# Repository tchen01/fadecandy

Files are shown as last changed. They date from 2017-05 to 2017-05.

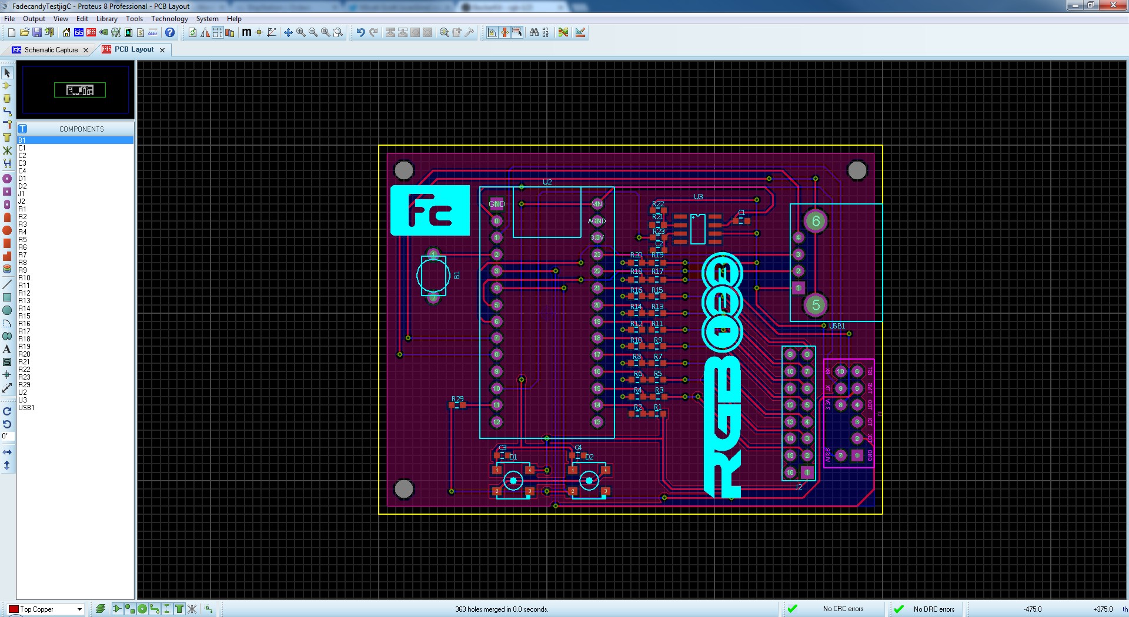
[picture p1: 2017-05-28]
pcb/testjig/FadeCandyTestJigC_ScreenCapture.jpg

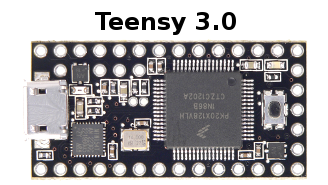
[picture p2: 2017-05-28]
pcb/teensy3/wiring-diagram.graffle/image1.png

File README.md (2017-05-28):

Fadecandy Title

Fadecandy is a project that makes LED art easier, tastier, and more creative. We're all about creating tools that remove the technical drudgery from making LED art, freeing you to do more interesting, nuanced, and creative things. We think LEDs are more than just trendy display devices, we think of them as programmable light for interactive art.

* [Video Introduction to Fadecandy](https://vimeo.com/79935649)
* [Introduction by Nick Poole from Spark Fun Electronics](https://www.youtube.com/watch?v=-4AUBjV7Y-w)
* [Tutorial: LED Art with Fadecandy](https://learn.adafruit.com/led-art-with-fadecandy)
* [Tutorial: 1,500 NeoPixel LED Curtain with Raspberry Pi and Fadecandy](https://learn.adafruit.com/1500-neopixel-led-curtain-with-raspberry-pi-fadecandy/)
* [Presentation slides: Easier and Tastier LED Art with Fadecandy](http://www.misc.name/easier-and-tastier-led-art-with-fadecandy/)
* [LED Interaction Research with Fadecandy at Stimulant labs](http://stimulant.com/led-interaction-research/)

Buy a Fadecandy Controller board:

* [Adafruit](http://www.adafruit.com/products/1689)
* [RGB-123](http://rgb-123.com/product/fadecandy/)



Simple Example
--------------

Here's a simple project, a single LED strip controlled by a Processing sketch running on your laptop:

Fadecandy system diagram 1

```
// Simple Processing sketch for controlling a 64-LED strip.
// A glowing color-blob appears on the strip under mouse control.

OPC opc;
PImage dot;

void setup()
{
  size(800, 200);

  // Load a sample image
  dot = loadImage("color-dot.png");

  // Connect to the local instance of fcserver
  opc = new OPC(this, "127.0.0.1", 7890);

  // Map one 64-LED strip to the center of the window
  opc.ledStrip(0, 64, width/2, height/2, width / 70.0, 0, false);
}

void draw()
{
  background(0);

  // Draw the image, centered at the mouse location
  float dotSize = width * 0.2;
  image(dot, mouseX - dotSize/2, mouseY - dotSize/2, dotSize, dotSize);
}
```

A More Complex Example
----------------------

Fadecandy is also useful for larger projects with many thousands of LEDs, and it's useful for art that runs on embedded computers like the Raspberry Pi:

Fadecandy system diagram 2

Project Scope
-------------

This project is a collection of reusable pieces you can take or leave. The overall goal of making LED art easier, tastier, and more creative is a broad one. To keep this project manageable to start with, there are some rough limitations on what's supported:

* LED strips, grids, and other modules based on the WS2811 or WS2812 chip.
  * Common and inexpensive, available from [many suppliers](http://www.aliexpress.com/item/5M-WS2811-LED-digital-strip-60leds-m-with-60pcs-WS2811-built-in-tthe-5050-smd-rgb/635563383.html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) for around $0.25 per pixel.
* Something with a USB host port that can run your art.
  * Laptops and Mac Minis work great
  * The Raspberry Pi is also a great platform for this, but it requires more technical skill
* Distances of no more than 60ft or so between your computer and your farthest LEDs
  * USB cables < 50ft
  * WS2811 data cables < 10ft
* No more than about 10000 LED pixels total
  * There's no hard limit, but it gets more difficult after this point.

These are fuzzy limitations based on current software capabilities and rough electrical limits, so you may be able to stretch them. But this gives you an idea about the kind of art we try to support. Projects are generally larger than wearables, but smaller than entire buildings.

For example, the first project to use Fadecandy was the [Ardent Mobile Cloud Platform](http://scanlime.org/2013/09/the-ardent-mobile-cloud-platform/) at Burning Man 2013. This project used one Raspberry Pi, five Fadecandy controller boards, and 2500 LEDs.

Fadecandy makes no assumptions about how you generate control patterns for the LEDs. You can generate a 2D video and sample pixels from the video, you can make a 3D model of your sculpture and sample a 3D *shader* for your pixel values, or you can create a unique system specifically for your art.

Fadecandy Controller
--------------------

The centerpiece of the Fadecandy project is a controller board which can drive up to 512 LEDs (as 8 strings of 64) over USB. Many Fadecandy boards can be attached to the same computer using a USB hub or a chain of hubs.

Fadecandy makes it easy to drive these LEDs from anything with USB, and it includes unique algorithms which eliminate many of the common visual glitches you see when using these LEDs.

The LED drive engine is based on Stoffregen's excellent [OctoWS2811](http://www.pjrc.com/teensy/td_libs_OctoWS2811.html) library, which pumps out serial data for these LED strips entirely using DMA. This firmware builds on Paul's work by adding:

* A high performance USB protocol
* Zero copy architecture with triple-buffering
* Interpolation between keyframes
* Gamma and color correction with per-channel lookup tables
* Temporal dithering
* A custom PCB with line drivers and a 5V boost converter
* A fully open source bootloader

These features add up to give *very smooth* fades and high dynamic range. Ever notice that annoying stair-stepping effect when fading LEDs from off to dim? Fadecandy avoids that using a form of [delta-sigma modulation](http://en.wikipedia.org/wiki/Delta-sigma_modulation). It rapidly wiggles each pixel's value up or down by one 8-bit step, in order to achieve 16-bit resolution for fades.

Vitals
------

* 512 pixels supported per Teensy board (8 strings, 64 pixels per string)
* Very high hardware frame rate (~400 FPS) to support temporal dithering
* Full-speed (12 Mbps) USB
* 257x3-entry 16-bit color lookup table, for gamma correction and color balance

Platform
--------

Fadecandy uses the Freescale MK20DX128 microcontroller, the same one used by the [Teensy 3.0](http://www.pjrc.com/store/teensy3.html) board. Fadecandy includes its own PCB design featuring a robust power supply and level shifters. It also includes an open source bootloader compatible with the USB Device Firmware Update spec.

You can use Fadecandy either as a full hardware platform or as firmware for the Teensy 3.0 board.

Color Processing
----------------

Fadecandy internally represents colors with 16 bits of precision per channel, or 48 bits per pixel. Why 48-bit color? In combination with our dithering algorithm, this gives a lot more color resolution. It's especially helpful near the low end of the brightness range, where stair-stepping and color *popping* artifacts can be most apparent.

Each pixel goes through the following processing steps in Fadecandy:

* 8 bit per channel framebuffer values are expanded to 16 bits per channel
* We interpolate smoothly from the old framebuffer values to the new framebuffer values
* This interpolated 16-bit value goes through the color LUT, which itself is linearly interpolated
* The final 16-bit value is fed into our temporal dithering algorithm, which results in an 8-bit color
* These 8-bit colors are converted to the format needed by OctoWS2811's DMA engine
* In hardware, the converted colors are streamed out to eight LED strings in parallel

The color lookup tables can be used to implement gamma correction, brightness and contrast, and white point correction. Each channel (RGB) has a 257 entry table. Each entry is a 16-bit intensity. Entry 0 corresponds to the 16-bit color 0x0000, entry 1 corresponds to 0x0100, etc. The 257th entry corresponds to 0x10000, which is just past the end of the 16-bit intensity space.

Keyframe Interpolation
----------------------

By default, Fadecandy interprets each frame it receives as a keyframe. In-between these keyframes, Fadecandy will generate smooth intermediate frames using linear interpolation. The interpolation duration is determined by the elapsed time between when the final packet of one frame is received and when the final packet of the next frame is received.

This scheme works well when frames are arriving at a nearly constant rate. If frames suddenly arrive slower than they had been arriving, interpolation will proceed faster than it optimally should, and one keyframe will hold steady until the next keyframe arrives. If frames suddenly arrive faster than they had been arriving, Fadecandy will need to jump ahead in order to avoid falling behind.

This keyframe interpolation is not intended as a substitute for other forms of animation control. It is intended to generate high-framerate video from a source that operates at typical video framerates.

Open Pixel Control Server
-------------------------

The Fadecandy project includes an [Open Pixel Control](http://openpixelcontrol.org/) server which can drive multiple Fadecandy boards and DMX adaptors. USB devices may be hotplugged while the server is up, and the server uses a JSON configuration file to map OPC messages to individual Fadecandy boards and DMX devices.

Why use Open Pixel Control?

* You can keep your effects code portable among different lighting controllers.
* OPC includes an OpenGL-based simulator, allowing you to develop effects before the hardware is done.
* The OPC server manages USB hotplug and multi-device synchronization, so you don't have to.
* The OPC server loads color-correction data into each Fadecandy board.

WebSockets Server
-----------------

In addition to Open Pixel Control, `fcserver` also supports WebSockets, so you can write LED art algorithms and utilities in Javascript using the plethora of libraries and tools available on that platform. LED art can be easily integrated with any input device or library that will run in the browser or Node.

Browser UI
----------

When you run `fcserver`, it also gives you a simple browser-based UI for identifying the attached Fadecandy Controllers and quickly testing your lights. By default, this UI runs on [http://localhost:7890](http://localhost:7890).

Browser UI Screenshot

Where to?
---------

* [Video introduction by Nick Poole from Spark Fun Electronics](https://www.youtube.com/watch?v=-4AUBjV7Y-w)
* Tutorial: ["LED Art with Fadecandy"](https://learn.adafruit.com/led-art-with-fadecandy)
* Sample projects are in [examples](https://github.com/scanlime/fadecandy/tree/master/examples)
* Pre-compiled binaries are in [bin](https://github.com/scanlime/fadecandy/tree/master/bin)
* More documentation is included in [doc](https://github.com/scanlime/fadecandy/tree/master/doc)
  * [Open Pixel Control Protocol](https://github.com/scanlime/fadecandy/blob/master/doc/fc_protocol_opc.md)
  * [WebSocket Protocol](https://github.com/scanlime/fadecandy/blob/master/doc/fc_protocol_websocket.md)
  * [USB Protocol](https://github.com/scanlime/fadecandy/blob/master/doc/fc_protocol_usb.md)
  * [Processing OPC Client](https://github.com/scanlime/fadecandy/blob/master/doc/processing_opc_client.md)
  * [Server Configuration](https://github.com/scanlime/fadecandy/blob/master/doc/fc_server_config.md)
  * ...or if you still have questions, ask the [discussion group](https://groups.google.com/forum/#!forum/fadecandy)
* Buy a Fadecandy Controller board
  * [Adafruit](http://www.adafruit.com/products/1689)
  * [RGB-123](http://rgb-123.com/product/fadecandy/)

Frequently Asked Questions
--------------------------

### Why can't you use more than 64 LEDs per strip?

This limit comes from the data rate of the WS2811 LED controller's protocol (800 kbps) and the frame rate that seems to be needed to get the best results from our temporal dithering algorithm (about 400 FPS).

With the WS2811 protocol, each bit takes 1.25 microseconds to transmit, and there's a 50 microsecond reset state that happens once per frame. Each LED has 24 bits of data. We can use this to relate number of LEDs to frames per second:

```
(a)   fps = 1 / ( 0.00000125 * 24 * numLEDs + 0.00005 )
(b)   numLEDs = floor( (1 / fps - 0.00005) / 0.00000125 / 24 )
```

Equation (a) tells us that the theoretical maximum frame rate for 64 LEDs is 507.6 FPS. The Fadecandy Controller actually gets more like 425 FPS most of the time, since the CPU speed tends to be the limiting factor. With Equation (b), we can see that a theoretical strip length of 81 would still let us get 403 FPS. So why did I choose 64 instead of 81? Powers of two, mostly, and I honestly chose the limit of 64 before I knew exactly what frame rates would be necessary.

It would be possible to drive LED strips of around 80 LEDs in length with the same quality using a slightly more powerful microcontroller, as long as we don't rely on the strip length to be a power of two.

### Will Fadecandy work on the Teensy 3.1 board?

Currently, no. The Teensy 3.1 uses a different microcontroller with a slightly different memory layout which would make it impractical to have one firmware image that's binary-compatible with both the Teensy 3.1 and the Teensy 3.0 / Fadecandy Controller board. This is a thing that's certainly doable, but I haven't wanted to spend the extra maintenance effort to maintain and test a binary image for a second architecture.

If anyone reading is passionate about supporting the Teensy 3.1 and would volunteer to maintain a port, I'd be happy to point you toward the modifications that would be necessary.

### Would Fadecandy be able to take advantage of the additional processing power on the Teensy 3.1's microcontroller?

A little bit, maybe! But it wouldn't be a dramatic improvement, if we wanted to keep the exact same quality of dithering.

With some extra processing power and RAM, the strip length limit could be increased from 64 to around 80. This is hardly a dramatic increase, though. The intrinsic limits explained above are more of a factor in the design than the CPU or RAM limits.

### Can you use multiple Fadecandy controllers at once?

Yes! You can use USB hubs to connect many Fadecandy boards to one controller.

### What are the limits? How big can Fadecandy go?

Fadecandy limits include USB bus bandwidth, Open Pixel Control packet size, and CPU power. 

USB Bus bandwidth will start to be a problem around a dozen Fadecandy boards per USB host controller. This may start to depend on the details of the computer you're using. On a laptop, each USB port will usually have an independent allocation of bandwidth available. So, connect the first dozen Fadecandy boards to one USB port, then the second dozen to another USB port, etc. If you do connect more than the recommended number of Fadecandy controllers to one port they'll still work, but frame rate will start to decrease.

The [Open Pixel Control](http://openpixelcontrol.org/) protocol used by Fadecandy has a packet size limit of 64 kilobytes, or 21845 LEDs. Any more than that will require workarounds, such as extending the OPC protocol or using multiple OPC channels.

And then there's CPU power... these limits will depend on the language and framework your code uses, and what kind of computer you're running from. A large installation with 10,000 LEDs will probably need to run off of a laptop or Mac Mini unless your code is quite efficient. Smaller installations with up to 1000 LEDs or so could run off of something as small as a Raspberry Pi. But these are very broad generalizations, and this all depends on how much processing you need to perform per-LED. Keep in mind the scalability levels of your particular framework when you plan to build a large installation.

### The Raspberry Pi is kind of slow. What other small embedded Linux computers are available?

There are a lot of options to choose from, but my current favorite is the [ODROID-U3](http://www.hardkernel.com/main/products/prdt_info.php?g_code=G138745696275). It's about the same size as a Raspberry Pi, with a 1.7 GHz quad-core ARM. There's an optional fan add-on, but I haven't found it to be necessary yet.

### I'm using Windows 7, and the driver for Fadecandy doesn't load. What can I do?

Make sure you have all available Windows updates installed. Fadecandy uses a Windows feature ([WCID](https://github.com/pbatard/libwdi/wiki/WCID-Devices)) that wasn't present in the original retail version of Windows 7, but it was added in a subsequent update.

For reference, this is a 
[series of screenshots](http://imgur.com/a/0MAFR) showing a Fadecandy controller attached to a freshly installed Windows 7 Home Professional 32-bit virtual machine. At first it fails (no driver for "Fadecandy") but after updating Windows, it finds the correct device (WinUSB) and fcserver connects to it.

If that doesn't fix it, you may have a version of Windows with an inexplicably broken `WinUSB` driver. The French version of Windows 7 SP1 seems to be afflicted by this bug, and possibly others. As a workaround, you can use the [Zadig](http://zadig.akeo.ie/) utility to manually install an alternative driver. Use the arrows to change the driver on the right side of the arrow from `WinUSB` to `libusbK`, then click "Install Driver". You can see a [series of screenshots](http://imgur.com/a/25V81) illustrating this.

If you're still having trouble, please ask for help on the [discussion group](https://groups.google.com/forum/#!forum/fadecandy) or [bug tracker](https://github.com/scanlime/fadecandy/issues) and we can get to the bottom of this problem together. Thanks for your patience!

Contact
-------

Please direct questions to the [Discussion group](https://groups.google.com/forum/#!forum/fadecandy), it's full of smart and creative people who can help!

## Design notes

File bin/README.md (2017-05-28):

Fadecandy: Pre-compiled Binaries
================================

This directory contains convenient precompiled firmware and server binaries for Fadecandy. This file explains the conventions for the various types of files here.

Fadecandy Server
----------------

* `fcserver-osx`
  * Ready-to-run fcserver for Mac OS 10.6 and later
* `fcserver.exe`
  * Ready-to-run fcserver for Windows 7 and later
* `fcserver-rpi`
  * Ready-to-run fcserver for Raspberry Pi
  * May also work on other ARM Linux distributions
  * Requires root privileges and/or special usbfs configuration

Firmware Images
---------------

* `fc-boot-v###.hex`
  * Bootloader image only, in Intel Hex format.
  * This can be combined with other images to create a bootloader plus firmware image, or you can burn it alone and flash firmware separately using dfu-util.
  * For use with Teensy Loader, JTAG debuggers, or the Testjig.
* `fc-firmware-v###.hex`
  * Firmware image, including bootloader, in Intel Hex format.
  * For use with Teensy Loader, JTAG debuggers, or the Testjig.
  * Since this includes the bootloader, it can be updated with dfu-util if necessary.
* `fc-firmware-v###.elf`
  * ELF binary for the firmware. Includes debug symbols. Does NOT include the bootloader.
  * For use with GDB. Also used to generate Testjig firmware images.
  * Mainly used as a source file for generating other types of firmware images. You probably won't use it directly.
* `fc-firmware-v###.dfu`
  * Firmware image for DFU firmware updates.
  * For use with dfu-util to update firmware without any special debug hardware.
  
Firmware Update Tool
--------------------

Firmware updates use the open source [dfu-util](http://dfu-util.gnumonks.org/) package.

Usage:

`$ dfu-util -D fc-firmware-v###.dfu`

* On Windows, you may need to run this multiple times as Windows will need to install drivers automatically for the Bootloader device.
* First the Fadecandy board will go into bootloader mode. The LED will light.
* Next, firmware will download. During this process, the LED blinks.
* When the firmware download is done, the LED will go dark.

For example:

	$ dfu-util -D fc-firmware-v106.dfu
	dfu-util 0.7

	Copyright 2005-2008 Weston Schmidt, Harald Welte and OpenMoko Inc.
	Copyright 2010-2012 Tormod Volden and Stefan Schmidt
	This program is Free Software and has ABSOLUTELY NO WARRANTY
	Please report bugs to dfu-util@lists.gnumonks.org
	
	Opening DFU capable USB device... ID 1d50:6082
	Run-time device DFU version 0101
	Found DFU: [1d50:6082] devnum=0, cfg=1, intf=0, alt=0, name="Fadecandy Bootloader"
	Claiming USB DFU Interface...
	Setting Alternate Setting #0 ...
	Determining device status: state = dfuIDLE, status = 0
	dfuIDLE, continuing
	DFU mode device DFU version 0101
	Device returned transfer size 1024
	Dfu suffix version 100
	bytes_per_hash=296
	Copying data from PC to DFU device
	Starting download: [##################################################] finished!
	state(7) = dfuMANIFEST, status(0) = No error condition is present
	state(7) = dfuMANIFEST, status(0) = No error condition is present
	...

* Windows: `dfu-util.exe` is included here, for convenience
* Mac OS: Install this with [homebrew](http://brew.sh): `brew install dfu-util`
* Linux: dfu-util is probably in your favorite package manager

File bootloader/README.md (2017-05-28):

Fadecandy Bootloader
====================

This is a simple open source bootloader for the Freescale Kinetis MK20DX128 microcontroller. It uses the USB Device Firmware Upgrade (DFU) standard. This bootloader was developed for use with Fadecandy, but it should be portable with to other projects using chips in the Kinetis microcontroller family.

Installing
----------

On a Teensy 3.0, you can use the Teensy Loader application to install `fc-boot.hex`. Afterwards, your Teensy should appear to the system as a "Fadecandy Bootloader" USB device capable of loading an application firmware image.

On a Fadecandy fc64x8 board, the bootloader can be installed via JTAG using OpenOCD. If you have an Olimex ARM-USB-OCD adapter, everything's already set up to install the bootloader with "make install". Other JTAG adapters will require changing `openocd.cfg`.

Application Interface
---------------------

This section describes the programming interface that exists between the bootloader and the application firmware.

The bootloader uses the smallest possible protected region on the MK20DX128's flash, a 4KB block. It uses a tiny amount of RAM for a "token" which is used to force entry into the bootloader on system reset.

When entering the application firmware, the system clocks will already be configured, and the watchdog timer is already enabled with a 10ms timeout. The application may disable the watchdog timer if desired.

The bootloader normally transfers control to the application early in boot, before setting up the USB controller. It will skip this step and run the DFU implementation if any of the following conditions are true:

* A banner ("FC-Boot\n") printed to the hardware UART at 9600 baud is echoed back within one character-period. (Manual entry by shorting TX and RX)
* A 32-bit entry token (0x74624346, or 'FCbt') is found at 0x2000_1FFC. (Programmatic entry)
* The application ResetVector does not reside within application flash. (No application is installed)

Memory address range       | Description
-------------------------- | ----------------------------
0x0000_0000 - 0x0000_0FFF  | Bootloader protected flash
0x0000_1000 - 0x0000_10F7  | Application IVT in flash
0x0000_1000 - 0x0001_FFFF  | Remainder of application flash
0x1FFF_E000 - 0x2000_1FFC  | Application SRAM
0x2000_1FFC - 0x2000_1FFF  | Entry token in SRAM

External Hardware
-----------------

No external hardware is required for the bootloader to operate. The following pins are used by the bootloader for optional features:

* PC5 is a status LED, active (high) while the bootloader is in DFU mode.
* PCR16/17 are set up as UART0 briefly during boot, for broadcasting the banner message and testing for manual bootloader entry.

File Format
-----------

The DFU file consists of raw 1 kilobyte blocks to be programmed into flash starting at address 0x0000_1000. The file may contain up to 127 blocks. No additional headers or checksums are included. On disk, the standard DFU suffix and CRC are used. During transit, the standard USB CRC is used.

Contact
-------

Micah Elizabeth Scott <<micah@scanlime.org>>

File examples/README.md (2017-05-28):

Fadecandy Example Code
======================

This directory contains sample projects and configuration files for Fadecandy.

* `processing`
  * Examples for [Processing 2](http://processing.org/), a popular tool for creative coding
* `html`
  * Browser-based examples, written in JavaScript with HTML5
* `node`
  * JavaScript examples for Node.js
* `cpp`
  * Examples written in C++
  * Includes a small header-only effects framework you can copy and reuse
  * Suitable for resource-constrained systems or very CPU-intensive patterns
  * Currently supports Linux and Mac OS X only.
* `python`
  * Some examples written in [Python](http://python.org/)
* `config`
  * Sample JSON configuration files for `fcserver`
* `layouts`
  * JSON layout files and layout generators
  * Compatible with the Open Pixel Control `gl_server`.
  * Compatible with some of the Node.js examples.

LED Layouts
-----------

Some examples are written for a specific LED layout or art project, some examples are general-purpose. For examples that use a specific LED layout, we indicate this with a naming convention. For example, if a project "potato" were written for a 48x24 grid, it would be named "grid48x24_potato".

Some of the generic examples (Specifically, the C++ and Node.js ones) can load separate layout files. These are in the same JSON notation used by the [Open Pixel Control](http://openpixelcontrol.org) project, and we use the same naming scheme for those JSON files.

Layout names we use so far:

* grid8x8 - A simple left-to-right top-to-bottom 8x8 pixel grid
  * For example, the [AdaFruit NeoMatrix](http://www.adafruit.com/products/1487)
* grid24x8z - Three 8x8 zig-zag grids side by side
  * Channel 0 is the center, and may be used alone.
  * For example, three of the 8x8 grids from [RGB-123](http://www.kickstarter.com/projects/311408456/rgb-123-led-matrices)
* grid32x8z - A 4x2 grid of 8x8 zig-zag grids
  * Channel 0 is the top-left grid, channel 7 is the bottom-right
  * For example, eight of the 8x8 grids from [RGB-123](http://www.kickstarter.com/projects/311408456/rgb-123-led-matrices)
* strip64 - A single 64-pixel LED strip
* triangle16 - A subdivided equilateral triangle with 16 pixels
* window6x12 - A complex window display layout made from glass blocks
  * This example shows how additional properties other than location may be stored in the JSON file.

More Examples
-------------

There are other places to look for example code too!

* The [Open Pixel Control](https://github.com/zestyping/openpixelcontrol) project
  * Everything here will work with Fadecandy, including their [Python examples](https://github.com/zestyping/openpixelcontrol/tree/master/python_clients)
* The [Ardent Mobile Cloud Platform source code](https://github.com/ArdentHeavyIndustries/amcp-rpi)
  * The [AMCP](http://scanlime.org/2013/09/the-ardent-mobile-cloud-platform/) is the first art project to use Fadecandy.
  * It controls 2500 LEDs with five Fadecandy boards and a Raspberry Pi.
  * The software is written in Python, with a C extension to accelerate the LED effects.
  * It's controlled over Wi-fi, by a [TouchOSC](http://hexler.net/software/touchosc) remote control.

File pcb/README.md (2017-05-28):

Fadecandy Controller Boards
===========================

This directory contains information and design files for the various circuit boards that you can run Fadecandy firmware on.

Teensy 3.0
----------

The [Teensy 3.0](http://www.pjrc.com/teensy/) microcontroller board from PJRC was the original development platform for Fadecandy. You can still run the Fadecandy firmware, including the bootloader, on this platform.

* Use the [Teensy Loader](http://www.pjrc.com/teensy/loader.html) to install a [Firmware Binary](https://raw.github.com/scanlime/fadecandy/master/bin/fc-firmware-v106.hex) on your Teensy 3.0
* Bridge pins 15 and 16
* Wire your LEDs according to the diagram:

**Warning:** The Teensy's output signals are 3.3V, whereas the WS2811 LEDs expect a 5V signal. It will often work anyway, but this tends to be unreliable if your LED power supply voltage isn't consistent or if your wires aren't very short.

Teensy 3.0 wiring diagram

Fc64x8 Revision A
-----------------
 
This board uses the same microcontroller as the Teensy 3.0 board, a Freescale Kinetis K20. There are several differences from the Teensy 3.0, however, that make it easier to use and more reliable for LED applications:

* It comes pre-programmed with the Fadecandy firmware.
* The Fadecandy board has a more convenient pinout, with more ground pads and with the LED strings organized sensibly.
* The Teensy uses 3.3v IO which doesn't work reliably with the WS2811 LEDs. Fadecandy includes a level shifter and series termination resistors.
* Fadecandy also includes a boost converter power supply to generate a stable 5V for the level shifter even when the USB power is noisy or sagging due to long cables.
* The Teensy uses a proprietary bootloader implemented on a separate microcontroller. The Fadecandy board has an open source bootloader that runs on the same microcontroller as the firmware, and it speaks the standard DFU protocol.

The PCB design for this revision is tagged as **fc64x8-rev-a** in Git. This board was manufactured in a limited run of 100, and availability has been very limited.

* [PCB Design Files](https://github.com/scanlime/fadecandy/tree/fc64x8-rev-a/pcb/fc64x8)
* Design software is [Eagle CAD](http://www.cadsoftusa.com/)

Fc64x8-a Photo

Fc64x8 Revision B
-----------------

Electrically the same as Revision A, this is the version produced by Adafruit. It is slightly larger, at 0.8" by 1.25". It uses a mini-USB instead of a micro-USB connector, and includes two extra small holes at the top corners for mounting onto larger boards.

RGB-123 Fadecandy Controller
----------------------------

This is a new board layout for Fadecandy which uses different component packages. It is produced and sold by Ryan O'Hara at RGB-123. The current version is Revision G.

Test Jig
--------

This board, with the help of a Teensy 3.0 and the testjig firmware, performs automated factory tests and firmware installation on Fadecandy boards.

The design was contributed by Ryan O'Hara of RGB-123.

* [Order PCBs via OSH Park](http://oshpark.com/shared_projects/0Hx8kSYR)
* Design software is [LabCenter Proteus](http://www.labcenter.co.uk/)

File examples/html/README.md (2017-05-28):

Fadecandy HTML5 Examples
========================

This directory contains examples for Fadecandy written in JavaScript with HTML5.

Stable Examples
---------------

* `grid8x8_dots`
  * A springy trail of glowing dots that follows the mouse
  * Uses [Paper.js](http://paperjs.org/)
  * Set up for an 8x8 grid in left-right top-down order
  * Browser support
    * **Firefox**: Works great
    * **Chrome**: Okay, but not as smooth as Firefox
    * **Safari**: Stops running after a couple seconds 

Additional Examples
-------------------

* `grid24x8z_dots` -- Modification of grid8x8 dots for the grid24x8z layout
* `grid24x8z_dots_leapmotion` -- Very experimental example with Leap Motion control

See Also
--------
 
* The fcserver Web UI
   * Uses the JSON interface to `fcserver`
   * Illustrates device hotplug, and bypassing the OPC pixel mapping
   * Try it out at [http://localhost:7890](http://localhost:7890) when fcserver is running
   * Source code at [fadecandy/server/http/js/home.js](https://github.com/scanlime/fadecandy/blob/master/server/http/js/home.js)

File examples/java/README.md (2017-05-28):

opc_client
==========

Simple Java OPC client for the [Fadecandy](http://www.misc.name/fadecandy/).
This is an alternative to the Processing client, providing a simpler interface similar to Adafruit's [NeoPixel library for Arduino](https://github.com/adafruit/Adafruit_NeoPixel).

# Writing simple pixel programs

Here is a simple Java program that will color some of the lights:

```
    public static void main(String[] args) throws Exception {
        OpcClient server = new OpcClient("10.28.46.61", 7890);
        OpcDevice fadecandy = server.addDevice();
        PixelStrip strip = fadecandy.addPixelStrip(0, 64);
        
        int color = 0xFF0000;  // red
        strip.setPixelColor(3, color);
        strip.setPixelColor(5, 0x888800); // yellow
        strip.setPixelColor(7, 0x00FF00); // green
        
        server.show();        // Display the pixel changes
        Thread.sleep(5000);   // Wait five seconds
        server.clear();       // Set all pixels to black
        server.show();        // Show the darkened pixels
        
        server.close();
    }
```

# Animations
We can also create Animation classes which will draw different patterns over and over.  We can attach animations to any given pixel strip.  When we attach a new animation object, the light patterns will change.

```
public class RandomPixels extends Animation {

    java.util.Random rand;
    
    public void reset(PixelStrip strip) {
        rand = new java.util.Random();
    }

    public boolean draw(PixelStrip strip) {
        int randomPixel = rand.nextInt(strip.getPixelCount());
        int randomColor = makeColor(rand.nextInt(255), 
                         rand.nextInt(255), rand.nextInt(255));
        strip.setPixelColor(randomPixel, randomColor);
        return true;
    }
}
```

# Server Configuration

The Fadecandy has eight pins, each of which can control a strip of 64 pixels.
If you have contiguous strips of pixels starting on pin zero, then your `fc_server` won't need to map the output pixels numbers to configurable OPC numbers.  However, if you have
shorter strips connected to different pins, you may want to set up a [JSON configuration file](https://github.com/scanlime/fadecandy/blob/master/doc/fc_server_config.md)
for the server.  The `OpcClient` class can print out a JSON configuration based on
strip definitions:

```
public static void main(String[] arg)  {
    OpcClient server = new OpcClient("raspberrypi.local", 7980);
    OpcDevice fadeCandy = server.addDevice();
        
    PixelStrip strip1 = fadeCandy.addPixelStrip(0, 64);  // 8 x 8 grid on pin 0
    PixelStrip strip2 = fadeCandy.addPixelStrip(1, 8);   // 8 pixel strip on pin 1
    PixelStrip strip3 = fadeCandy.addPixelStrip(2, 16);  // 16 pixel ring on pin 2
    PixelStrip strip4 = fadeCandy.addPixelStrip(3, 24);  // The first 24 pixels on pin 3
    PixelStrip strip5 = fadeCandy.addPixelStrip(3, 17);  // The next 17 pixels on pin 3
        
    // Since the pixels are not uniform strips of 64, customize 
    // the server config JSON file with the following:
    System.out.println(server.getConfig());
}
```

For the above setup, the JSON server configuration should be:

```
{
    "listen": [ "raspberrypi.local", 7890],
    "verbose": true,
    "devices": [
        {
            "type": "fadecandy",
            "map": [

                    [0, 0, 0, 64 ],
                    [0, 64, 64, 8 ],
                    [0, 72, 128, 16 ],
                    [0, 88, 192, 24 ],
                    [0, 112, 216, 17 ]
                ]
        }   ]
}
```

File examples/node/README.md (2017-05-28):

Fadecandy Node.js Examples
==========================

This directory contains examples for Fadecandy written in [Node.js](http://nodejs.org/).

Stable Examples
---------------

* `strip_redblue`
  * An example for LED strips. A fade of blue, white, and red washes across the LEDs.

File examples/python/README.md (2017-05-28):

Fadecandy Python Examples
========================

This directory contains examples for Fadecandy written in Python.

The Open Pixel Control project includes its own [Python examples](https://github.com/zestyping/openpixelcontrol/tree/master/python_clients). Those will all work with Fadecandy too.

Simple LED Patterns
-------------------

* `chase.py`
  * Light each LED in sequence
* `crosstalk-test.py`
  * Each LED strip glows dimly, and one strip at a time will briefly brighten.
  * The first three pixels of each strip indicate its position on the controller.
  * This is intended as a hardware test pattern to isolate any electrical interference issues between strips.
* `every-other-white.py`
  * Alternate between full-brightness and dark every other LED.
* `measuring-stick.py`
  * A tool for measuring LED strips.
  * The first LED in each group of 10 glows green.
  * All other LEDs in the strip are dark.
  * LEDs past the first 64 in the strip will be dark.
* `solid-white.py`
  * Fade all LEDs in to 100% brightness
* `strobe.py`
  * Rapidly fade all LEDs on and off

Other Samples
-------------

* `color-correction-ui.py`
  * Tk user interface for adjusting color correction settings.
  * Connects directly to `fcserver`
* `firmware-config-ui.py`
  * Tk user interface for firmware configuration settings.
  * Connects directly to `fcserver`
* `usb-lowlevel.py`
  * Demonstrates low-level USB control of a Fadecandy board, without `fcserver`.
  * Uses PyUSB

Sample Libraries
----------------

* `opc.py`
  * Original Open Pixel Control client
* `fastopc.py`
  * Higher-performance OPC client, using NumPy

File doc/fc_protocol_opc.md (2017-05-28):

Fadecandy: Open Pixel Control Protocol
======================================

The Fadecandy Server (`fcserver`) operates as a bridge between LED controllers attached over USB, and visual effects that communicate via a TCP socket.

The primary protocol supported by `fcserver` is [Open Pixel Control](http://openpixelcontrol.org), a super simple way to send RGB values over a socket. We support the standard Open Pixel Control commands, as well as some Fadecandy extensions.

Socket
------

Open Pixel Control uses a TCP socket, by default on port 7890. For the best performance, remember to set TCP_NODELAY socket option.

Command Format
--------------

All OPC commands follow the same general format. All multi-byte values in Open Pixel Control are in network byte order, high byte followed by low byte.

Channel    | Command   | Length (N) | Data
---------- | --------- | ---------- | --------------------------
1 byte     | 1 byte    | 2 bytes    | N bytes of message data

Set Pixel Colors
----------------

Video data arrives in a **Set Pixel Colors** command:

Byte   | **Set Pixel Colors** command
------ | --------------------------------
0      | Channel Number
1      | Command (0x00)
2 - 3  | Data length
4      | Pixel #0, Red
5      | Pixel #0, Green
6      | Pixel #0, Blue
7      | Pixel #1, Red
8      | Pixel #1, Green
9      | Pixel #1, Blue
…      | …

As soon as a complete Set Pixel Colors command is received, a new frame of video will be broadcast simultaneously to all attached Fadecandy devices.

Set Global Color Correction
---------------------------

The color correction data (from the 'color' configuration key) can also be changed at runtime, by sending a new blob of JSON text in a Fadecandy-specific command. Fadecandy's 16-bit System ID for Open Pixel Control's System Exclusive (0xFF) command is **0x0001**.

Byte   | **Set Global Color Correction** command
------ | ------------------------------------------
0      | Channel Number (0x00, reserved)
1      | Command (0xFF, System Exclusive)
2 - 3  | Data length (JSON Length + 4)
4 - 5  | System ID (0x0001, Fadecandy)
6 - 7  | SysEx ID (0x0001, Set Global Color Correction)
8 - …  | JSON Text

Set Firmware Configuration
--------------------------

The firmware supports some runtime configuration options. Any OPC client can send a new firmware configuration packet using this command. If the supplied data is shorter than the firmware's configuration buffer, only the provided bytes will be changed.

Byte   | **Set Firmware Configuration** command
------ | ------------------------------------------
0      | Channel Number (0x00, reserved)
1      | Command (0xFF, System Exclusive)
2 - 3  | Data length (Configuration Length + 4)
4 - 5  | System ID (0x0001, Fadecandy)
6 - 7  | SysEx ID (0x0002, Set Firmware Configuration)
8 - …  | Configuration Data

Current firmwares support the following configuration options:

Byte Offset | Bits   | Description
----------- | ------ | ------------
0           | 7 … 4  | (reserved)
0           | 3      | Manual LED control bit
0           | 2      | 0 = LED shows USB activity, 1 = LED under manual control
0           | 1      | Disable keyframe interpolation
0           | 0      | Disable dithering
1 … 62      | 7 … 0  | (reserved)

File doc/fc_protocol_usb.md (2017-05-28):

Fadecandy: USB Protocol
=======================

To achieve the best CPU efficiency, Fadecandy uses a custom packet-oriented USB protocol rather than emulating a USB serial device. This simple USB protocol is easy to speak using cross-platform libraries like [libusb](http://www.libusb.org) and [PyUSB](http://pyusb.sourceforge.net/). Examples are included.

If you use the included `fcserver` daemon, you need not worry about the USB protocol at all.

Device Information
------------------

Attribute       | Value
--------------- | -----
Vendor ID       | 0x1d50
Product ID      | 0x607a
Manufacturer    | "scanlime"
Product         | "Fadecandy"
Serial          | Unique ID string
Device Class    | Vendor-specific
Device Version  | See below
Configurations  | 1
Endpoints       | 1
Endpoint 1      | Bulk OUT (Host to Device), 64-byte packets

The Fadecandy device has one USB Configuration with two Interfaces:

* **Interface #0** is a vendor-specific interface with one Bulk OUT endpoint for communicating control data and video keyframes.
* **Interface #1** is compatible with the USB Device Firmware Update spec. It's used during firmware upgrade to ask the device to enter bootloader mode. During normal operation, it's safe to ignore this interface.

Some device version codes may be used to indicate experimental or unofficial firmware. Currently, versions in the range 0x0300 through 0x03FF are reserved for unofficial Fadecandy firmware forks.

Getting Started
---------------

To use the Fadecandy Controller's USB protocol directly, you'll need to:

1. **Search** for the device you're interested in. You can look for all Fadecandy devices by looking at the Vendor and Product IDs. You can find a specific Fadecandy device by looking at its USB serial number string.
3. **Open** the device, and set its configuration. Depending on the operating system, you may also need to claim interface #0 so your application has exclusive access to it.
4. Set up a **Color Look-Up Table**. There is no default table, the firmware expects you to calculate one based on the gamma and whitepoint you'd like to use.
5. Send **Video Frames** at any time. When you complete a frame, the firmware immediately begins interpolating to it.

There's a [minimal example](https://github.com/scanlime/fadecandy/blob/master/examples/python/usb-lowlevel.py) written in Python using PyUSB. It calculates a simple Color LUT and sends random video frames.

To compare with the Color LUT calculation used by `fcserver`, see the [FCDevice::writeColorCorrection](https://github.com/scanlime/fadecandy/blob/47a4e551a71444923a1e6754f29f424e28a62090/server/src/fcdevice.cpp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) function in the fcserver source code.

Bulk Endpoint
-------------

The device has a single Bulk OUT endpoint which expects packets of up to 64 bytes. Multiple packets may be transmitted in one LibUSB "write" operation, as long as the buffer you provide is a multiple of 64 bytes in length.

Each packet begins with an 8-bit control byte, which is divided into three bit-fields:

Bits 7..6  | Bit 5       | Bits 4..0
---------- | ----------- | ------------
Type code  | 'Final' bit | Packet index

* The 'type' code indicates what kind of packet this is.
* The 'final' bit, if set, causes the most recent group of packets to take effect
* The packet index is used to sequence packets within a particular type code

The following packet types are recognized:

Type code | Meaning of 'final' bit          | Index range | Packet contents
--------- | ------------------------------- | ----------- | -------------------------------------
0         | Interpolate to new video frame  | 0 … 24      | Up to 21 pixels, 24-bit RGB
1         | Instantly apply new color LUT   | 0 … 24      | Up to 31 16-bit lookup table entries
2         | (reserved)                      | 0           | Set configuration data
3         |                                 |             | (reserved)

Video Packets
-------------

In a type 0 packet, the USB packet contains up to 21 pixels of 24-bit RGB color data. The last packet (index 24) only needs to contain 8 valid pixels. Pixels 9-20 in these packets are ignored.

Byte Offset   | Description
------------- | ------------
0             | Control byte
1             | Pixel 0, Red
2             | Pixel 0, Green
3             | Pixel 0, Blue
4             | Pixel 1, Red
5             | Pixel 1, Green
6             | Pixel 1, Blue
…             | …
61            | Pixel 20, Red
62            | Pixel 20, Green
63            | Pixel 20, Blue

Color LUT Packets
-----------------

In a type 1 packet, the USB packet contains up to 31 lookup-table entries. The lookup table is structured as three arrays of 257 entries, starting with the entire red-channel LUT, then the green-channel LUT, then the blue-channel LUT. Each packet is structured as follows:

Byte Offset   | Description
------------- | ------------
0             | Control byte
1             | Reserved (0)
2             | LUT entry #0, low byte
3             | LUT entry #0, high byte
4             | LUT entry #1, low byte
5             | LUT entry #1, high byte
…             | …
62            | LUT entry #30, low byte
63            | LUT entry #30, high byte

Configuration Packet
--------------------

A type 2 packet sets optional device-wide configuration settings:

Byte Offset | Bits   | Description
----------- | ------ | ------------
0           | 7 … 0  | Control byte
1           | 7 … 5  | (reserved)
1           | 4      | 0 = Normal mode, 1 = Reserved operation mode
1           | 3      | Manual LED control bit
1           | 2      | 0 = LED shows USB activity, 1 = LED under manual control
1           | 1      | Disable keyframe interpolation
1           | 0      | Disable dithering
2 … 63      | 7 … 0  | (reserved)

The "reserved operation mode" may be used by unofficial Fadecandy firmware that includes experimental or application-specific effects. This reserved bit is guaranteed not to be used during normal operation by future versions of fcserver.

Control Requests
----------------

In addition to the OUT endpoint, the device also supports vendor-specific control requests:

bmRequestType | bRequest | wValue | wIndex | wLength | Description
------------- | -------- | ------ | ------ | ------- | ---------------------------------------------
0xC0          | 0x01     | 0      | 0      | 4       | Read rendered frame counter (32-bit, little endian)
0xC0          | 0x01     | 0      | 1      | 4       | Read received keyframe counter (32-bit, little endian)
0xC0          | 0x7E     | x      | 4      | x       | Read Microsoft WCID descriptor
0xC0          | 0x7E     | x      | 5      | x       | Read Microsoft Extended Properties descriptor

USB Descriptors
---------------

For reference, this is sample output from the Mac OS X [USB Prober](https://developer.apple.com/library/mac/qa/qa1370/_index.html) diagnostics tool:

	Full Speed device @ 15 (0x14200000): Composite device: "Fadecandy"
	    Port Information:   0x101a
	           Not Captive
	           Attached to Root Hub
	           External Device
	           Connected
	           Enabled
	           Connected to External Port
	    Number Of Endpoints (includes EP0):   
	        Total Endpoints for Configuration 1 (current):   2
	    Device Descriptor   
	        Descriptor Version Number:   0x0200
	        Device Class:   0   (Composite)
	        Device Subclass:   0
	        Device Protocol:   0
	        Device MaxPacketSize:   64
	        Device VendorID/ProductID:   0x1D50/0x607A   (unknown vendor)
	        Device Version Number:   0x0108
	        Number of Configurations:   1
	        Manufacturer String:   1 "scanlime"
	        Product String:   2 "Fadecandy"
	        Serial Number String:   3 "ENICCULVLDQJQDWD"
	    Configuration Descriptor (current config)   
	        Length (and contents):   43
	            Raw Descriptor (hex)    0000: 09 02 2B 00 02 01 00 80  32 09 04 00 00 01 FF 00  
	            Raw Descriptor (hex)    0010: 00 00 07 05 01 02 40 00  00 09 04 01 00 00 FE 01  
	            Raw Descriptor (hex)    0020: 01 04 09 21 0D 10 27 00  04 01 01 
	        Number of Interfaces:   2
	        Configuration Value:   1
	        Attributes:   0x80 (bus-powered)
	        MaxPower:   100 mA
	        Interface #0 - Vendor-specific   
	            Alternate Setting   0
	            Number of Endpoints   1
	            Interface Class:   255   (Vendor-specific)
	            Interface Subclass;   0   (Vendor-specific)
	            Interface Protocol:   0
	            Endpoint 0x01 - Bulk Output   
	                Address:   0x01  (OUT)
	                Attributes:   0x02  (Bulk)
	                Max Packet Size:   64
	                Polling Interval:   0 ms
	        Interface #1 - Application Specific/Device Firmware Update "Fadecandy Bootloader"
	            Alternate Setting   0
	            Number of Endpoints   0
	            Interface Class:   254   (Application Specific)
	            Interface Subclass;   1   (Device Firmware Update)
	            Interface Protocol:   1
	            DFU Functional Descriptor   
	                bmAttributes:   0x0d (Download, No Upload, Manifestation Tolerant, Reserved bits: 0x08)
	                wDetachTimeout:   10000 ms
	                wTransferSize:   1024 bytes

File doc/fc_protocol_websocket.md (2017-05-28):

Fadecandy: WebSocket Protocol
=============================

The Fadecandy Server (`fcserver`) operates as a bridge between LED controllers attached over USB, and visual effects that communicate via a TCP socket.

The primary protocol supported by fcserver is [Open Pixel Control](http://openpixelcontrol.org), a super simple way to send RGB values over a socket. But in addition to OPC, fcserver also supports [WebSockets](http://www.websocket.org/) to allow clients to be written in Javascript.

Connecting
----------

To connect to fcserver, create a WebSocket. By default, fcserver listens on port 7890.

You can try this out in the Javascript Console in your web browser:

```
> ws = new WebSocket("ws://localhost:7890")
WebSocket {binaryType: "blob", extensions: "", protocol: "", onclose: null, onerror: null…}
```

In a real application, you'll also want to handle events like onopen() and onclose(). Take a look at the full [WebSockets API](http://dev.w3.org/html5/websockets/) if you haven't seen it yet.

Open Pixel Control Packets
--------------------------

Any binary packets sent over this socket are treated as Open Pixel Control packets. Since the WebSocket protocol includes its own length field, the original two length bytes in the OPC packet are reserved and should be sent as zero.

Channel    | Command   | Reserved (Zero) | Data
---------- | --------- | --------------- | --------------------------
1 byte     | 1 byte    | 2 bytes         | N bytes of message data

To send a binary packet, you can use [Typed Arrays](https://developer.mozilla.org/en-US/docs/Web/JavaScript/Typed_arrays). For example, this sets the first three LEDs to red, green, and blue respectively. (We send the packet twice to force interpolation to happen immediately, since we don't have a predictable frame rate when entering commands like this.)

```
> ws = new WebSocket("ws://localhost:7890")
> packet = new Uint8Array([ 0,0,0,0, 255,0,0, 0,255,0, 0,0,255 ]);
> ws.send(packet.buffer)
> ws.send(packet.buffer)
```

This is the recommended way of sending pixel data from a web app. The mapping settings from the fcserver config file take effect, and any OPC packet can be sent in this way.

JSON Packets
------------

Any WebSocket frames that contain text rather than binary data are expected to be JSON. These packets can be sent from client to server or from server to client. All JSON packets are objects with a "type" string.

Unless otherwise specified, all command packets that can be successfully parsed will generate replies by the server. If a problem occurred in processing the command, an "error" member will be added with an error message string to explain the problem. When the server replies to a command from the client, additional JSON object members in the command are preserved so clients can associate metadata with requests.

list_connected_devices
----------------------

This is sent from client to server to ask for a list of all connected devices:

```
{ "type": "list_connected_devices" }
```

The server will respond with a message like:

```
{
    "type": "list_connected_devices",
    "devices": [
        {
            "type": "fadecandy",
            "serial": "ENICCULVLDQJQDWD",
            "timestamp": 1384320928627,
            "version": "1.06",
            "bcd_version": 262
        }
    ]
}
```

Each device is a JSON object within a list of devices. Each device object must uniquely identify a particular connection of a particular device. Fields may include:

Name         | Description
------------ | -----------------------------------------------------------
type         | String identifying the device type ("fadecandy", "enttec")
serial       | Serial number for this particular device instance
timestamp    | When did this device connect? Timestamp in milliseconds
version      | Firmware version for the device, as a string
bcd_version  | BCD encoded firmware version, from the USB descriptors

connected_devices_changed
-------------------------

This packet can be sent unsolicited by the server any time a new device is attached or an existing device is removed. The response is identical to **list_connected_devices**, aside from the packet type.

server_info
-----------

This is sent from client to server to ask for information about the server itself:

```
{ "type": "server_info" }
```

The server will respond with a message like:

```
{
    "type": "server_info",
    "version": "fcserver-1.01",
    "config": {
        "listen": ["127.0.0.1",7890],
        "verbose": true,
        "color": {"gamma": 2.5, "whitepoint": [1,1,1]},
        "devices": [{"type": "fadecandy", "map": [[0,0,0,512]]}]
    }
}
```

Fields in the response include:

Name         | Description
------------ | --------------------------------------------------------------------
version      | Server version string
config       | JSON object with the server's current configuration file contents

device_color_correction
-----------------------

Write color correction info directly to a single device. Does not change the global color correction settings. The client first provides a message with color correction settings in the same format as the server's configuration file, and a device specification in the same format as **list_connected_devices**.

This example changes the whitepoint on a specific Fadecandy controller, to make the brightness very dim:

```
{
    "type": "device_color_correction",
    "device": {
        "type": "fadecandy",
        "serial": "ENICCULVLDQJQDWD"
    },
    "color": {
        "gamma": 2.5,
        "whitepoint": [0.2,0.2,0.2]
    }
}
```

device_options
--------------

Change the configuration options for a single device. This loads the same options supported by the server's JSON configuration file in the section for a single device.

For example, a Fadecandy device supports the following options:

Name         | Values               | Default | Description
------------ | -------------------- | ------- | --------------------------------------------
led          | true / false / null  | null    | Is the LED on, off, or under automatic control?
dither       | true / false         | true    | Is dithering enabled?
interpolate  | true / false         | true    | Is inter-frame interpolation enabled?

This example turns on the LED on a specific Fadecandy controller:

```
{
    "type": "device_options",
    "device": {
        "type": "fadecandy",
        "serial": "ENICCULVLDQJQDWD"
    },
    "options": {
        "led": true
    }
}
```

device_pixels
-------------

Sends pixel data directly to a single device, bypassing the OPC mapping. This accepts pixel data as an array of integers, and it's a lot less efficient than using OPC packets. This is mostly useful for special-purpose clients like configuration tools.

For example, setting the first three pixels to red, green, and blue for a specific Fadecandy controller:

```
{
    "type": "device_pixels",
    "device": {
        "type": "fadecandy",
        "serial": "ENICCULVLDQJQDWD"
    },
    "pixels": [
		255, 0, 0,
		0, 255, 0,
		0, 0, 255
    ]
}
```

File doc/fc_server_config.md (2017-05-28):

Fadecandy: Server Configuration
===============================

The Fadecandy Server is configured with a JSON object. There is a default configuration built-in, which you can see by running `fcserver -h`. A copy of this configuration is also included as [examples/config/default.json](https://github.com/scanlime/fadecandy/blob/master/examples/config/default.json).

A new configuration file can be given to `fcserver` on the command line in the following manner:

` $ <path to fcserver> <path to config.json file> `

You can use one of the examples as a starting point. Typically the default configuration will work for any single-controller setup. If you're using multiple controllers or there are other options you want to tweak, you'll want to create an fcserver configuration file for your project.

Parts of the JSON config format are shared with the network protocols. For example, color correction data and device information are stored in a common format. Some parts of the JSON configuration file can be modified at runtime.

Top-level Object
----------------

The configuration file is a JSON object. By default, it looks like this:

```
{
    "listen": ["127.0.0.1", 7890],
    "verbose": true,

    "color": {
        "gamma": 2.5,
        "whitepoint": [1.0, 1.0, 1.0]
    },

    "devices": [
        {
            "type": "fadecandy",
            "map": [
                [ 0, 0, 0, 512 ]
            ]
        }
    ]
}
```

Name     | Summary
-------- | -------------------------------------------------------
listen   | What address and port should the server listen on?
verbose  | Does the server log anything except errors to the console?
color    | Default global color correction settings
devices  | List of configured devices

Listen
------

By default, fcserver listens on port 7890 on the local (loopback) interface. This server will not be reachable by other computers on your network, only by programs on the same computer.

The "listen" configuration key must be a JSON array of the form [**host**, **port**], where **port** is a number and **host** is either a string or *null*. If the host is *null*, fcserver listens on all network interfaces and it's reachable from other computers

*Warning:* Do not run fcserver on an untrusted network. It has no built-in security provisions, so anyone on your network will have control of fcserver. Additionally, bugs in fcserver may compromise the security of your computer.

Color
-----

The "color" configuration key is a JSON object containing color correction data. This color correction data can also be changed at runtime by both the OPC and WebSocket interfaces. If instead of an object "color" is null, a linear (identity mapped) color table is used.

The default color configuration is:

```
"color": {
    "gamma": 2.5,
    "whitepoint": [0.98, 1.0, 1.0]
    "linearSlope": 1.0,
    "linearCutoff": 0.0
},
```

Supported keys in the "color" object are:

Name         | Description
------------ | -----------------------------------------------------------------
gamma        | Exponent for the nonlinear portion of the brightness curve
whitepoint   | Vector of [red, green, blue] values to multiply by colors prior to gamma correction
linearSlope  | Slope (output / input) of the linear section of the brightness curve
linearCutoff | Y (output) coordinate of intersection between linear and nonlinear curves

By default, brightness curves are entirely nonlinear. By setting linearCutoff to a nonzero value, though, a linear area may be defined at the bottom of the brightness curve.

The linear section, near zero, avoids creating very low output values that will cause distracting flicker when dithered. This isn't a problem when the LEDs are viewed indirectly such that the flicker is below the threshold of perception, but in cases where the flicker is a problem this linear section can eliminate it entierly at the cost of some dynamic range. To enable the linear section, set linearCutoff to some nonzero value. A good starting point is 1/256.0, correspnding to the lowest 8-bit PWM level.

Devices
-------

The JSON configuration file is a dictionary which contains global configuration and an array of device objects.

For each device, a dictionary includes device properties as well as a mapping table with commands which wire outputs to their corresponding OPC inputs. The map is a list of objects which act as mapping commands.

Fadecandy Devices
----------------- 

Supported mapping objects for Fadecandy devices:

* [ *OPC Channel*, *First OPC Pixel*, *First output pixel*, *Pixel count* ]
    * Map a contiguous range of pixels from the specified OPC channel to the current device
    * For Fadecandy devices, output pixels are numbered from 0 through 511. Strand 1 begins at index 0, strand 2 begins at index 64, etc.
* [ *OPC Channel*, *First OPC Pixel*, *First output pixel*, *Pixel count*, *Color channels* ]
    * As above, but the mapping between color channels and WS2811 output channels can be changed.
    * The "Color channels" must be a 3-letter string, where each letter corresponds to one of the WS2811 outputs.
    * Each letter can be "r", "g", or "b" to choose the red, green, or blue channel respectively, or "l" to use the average luminosity.

Other settings for Fadecandy devices:

Name         | Values               | Default | Description
------------ | -------------------- | ------- | --------------------------------------------
led          | true / false / null  | null    | Is the LED on, off, or under automatic control?
dither       | true / false         | true    | Is dithering enabled?
interpolate  | true / false         | true    | Is inter-frame interpolation enabled?

The following example config file supports two Fadecandy devices with distinct serial numbers. They both receive data from OPC channel #0. The first 512 pixels map to the first Fadecandy device. The next 64 pixels map to the entire first strand of the second Fadecandy device, and the next 32 pixels map to the beginning of the third strand with the color channels in Blue, Green, Red order.

    {
        "listen": ["127.0.0.1", 7890],
        "verbose": true,

        "color": {
            "gamma": 2.5,
            "whitepoint": [0.98, 1.0, 1.0]
        },

        "devices": [
            {
                "type": "fadecandy",
                "serial": "FFFFFFFFFFFF00180017200214134D44",
                "led": false,
                "map": [
                    [ 0, 0, 0, 512 ]
                ]
            },
            {
                "type": "fadecandy",
                "serial": "FFFFFFFFFFFF0021003B200314134D44",
                "map": [
                    [ 0, 512, 0, 64 ],
                    [ 0, 576, 128, 32, "bgr" ]
                ]
            }
        ]
    }

Using Open Pixel Control with DMX
---------------------------------

The Fadecandy server is designed to make it easy to drive all your lighting via Open Pixel Control, even when you're using a mixture of addressable LED strips and DMX devices.

For DMX, `fcserver` supports the common [Enttec DMX USB Pro adapter](http://www.enttec.com/index.php?main_menu=Products&pn=70304). This device attaches over USB, has inputs and outputs for one DMX universe, and it has an LED indicator. With Fadecandy, the LED will flash any time we process a new frame of video.

The Enttec adapter uses an FTDI FT245 USB FIFO chip internally. For the smoothest USB performance and the simplest configuration, we do not use FTDI's serial port emulation driver. Instead, we talk directly to the FTDI chip using libusb. On Linux this happens without any special consideration. On Mac OS, libusb does not support detaching existing drivers from a device. If you've installed the official FTDI driver, you can temporarily unload it until your next reboot by running:

    sudo kextunload -b com.FTDI.driver.FTDIUSBSerialDriver

Enttec DMX devices can be configured in the same way as a Fadecandy device. For example:

    {
            "listen": [null, 7890],
            "verbose": true,

            "devices": [
                    {
                            "type": "fadecandy",
                            "map": [
                                    [ 0, 0, 0, 512 ]
                            ]
                    },
                    {
                            "type": "enttec",
                            "serial": "EN075577",
                            "map": [
                                    [ 0, 0, "r", 1 ],
                                    [ 0, 0, "g", 2 ],
                                    [ 0, 0, "b", 3 ],
                                    [ 0, 1, "l", 4 ]
                            ]
                    }
            ]
    }

Enttec DMX devices use a different format for their mapping objects:

* [ *OPC Channel*, *OPC Pixel*, *Pixel Color*, *DMX Channel* ]
    * Map a single OPC pixel to a single DMX channel
    * The "Pixel color" can be "r", "g", or "b" to sample a single color channel from the pixel, or "l" to use an average luminosity.
    * DMX channels are numbered from 1 to 512.
* [ *Value*, *DMX Channel* ]
    * Map a constant value to a DMX channel; good for configuration modes

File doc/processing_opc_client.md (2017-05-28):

Open Pixel Control for Processing
=================================

The Processing examples included with Fadecandy use a very simple Open Pixel Control library, `OPC.pde`. A copy of this library is included with each example, and it's easy to get it into your own sketches by saving a copy of an example or copying the `template` sketch.

LED Mapping Example
-------------------

This OPC object makes it easy to map LEDs to specific locations on the screen. When you draw to the screen, the LEDs automatically update. The `strip64_dot` example sketch illustrates this:

```
OPC opc;
PImage dot;

void setup()
{
  size(800, 200);

  // Load a sample image
  dot = loadImage("color-dot.png");

  // Connect to the local instance of fcserver
  opc = new OPC(this, "127.0.0.1", 7890);

  // Map one 64-LED strip to the center of the window
  opc.ledStrip(0, 64, width/2, height/2, width / 70.0, 0, false);
}

void draw()
{
  background(0);

  // Draw the image, centered at the mouse location
  float dotSize = width * 0.2;
  image(dot, mouseX - dotSize/2, mouseY - dotSize/2, dotSize, dotSize);
}
```

Direct Control Example
----------------------

Alternatively, you can control the LEDs directly. Instead of automatically updating after every draw(), the LED colors are set explicitly and a packet is explicitly sent for every frame. This is illustrated in the `strip64_unmapped` example:

```
OPC opc;

void setup()
{
  opc = new OPC(this, "127.0.0.1", 7890);
  frameRate(10);
  colorMode(HSB, 100);
}

void draw()
{
  // RAINBOW FADE!!!!!
  for (int i = 0; i < 64; i++) {
    float hue = (millis() * 0.01 + i * 2.0) % 100; 
    opc.setPixel(i, color(hue, 20, 80));
  }

  // When you haven't assigned any LEDs to pixels, you have to explicitly
  // write them to the server. Otherwise, this happens automatically after draw().
  opc.writePixels();
}
```

Creating an OPC Object
----------------------

The examples above create an OPC object by first declaring a variable:

```
OPC opc;
```

Then, in **setup()**, they use *new* to create a new OPC instance:

```
opc = new OPC(this, "127.0.0.1", 7890);
```

The first parameter is the parent object. For a normal sketch, pass *this* as the first parameter. The next two parameters are the server name and port to connect to. This connects to fcserver on the same computer. If you've configured fcserver to allow connections from other computers, you can run your Processing sketch and fcserver on different machines.

Function Reference
------------------

This section lists all public methods available on the OPC object:

----

* **opc.led**(*index*, *x*, *y*)
  * Set the location of a single LED
  * *index*: LED number, starting with zero
  * *x*, *y*: Location on the screen, in pixels

----

* **opc.ledStrip**(*index*, *count*, *x*, *y*, *spacing*, *angle*, *reversed*)
  * Place a rigid strip of LEDs on the screen
  * *index*: Number for the first LED in the strip, starting with zero
  * *count*: How many LEDs are in the strip?
  * *x*, *y*: Center location, in pixels
  * *spacing*: Spacing between LEDs, in pixels
  * *angle*: Angle, in radians. Positive is clockwise, 0 is to the right.
  * *reversed*: true = Right to left, false = Left to right

----

* **opc.ledGrid**(*index*, *stripLength*, *numStrips*, *x*, *y*, *ledSpacing*, *stripSpacing*, *angle*, *zigzag*)
  * Place a rigid grid of LEDs on the screen
  * *index*: Number for the first LED in the grid, starting with zero
  * *stripLength*: How long is each strip in the grid?
  * *numStrips*: How many strips of LEDs make up the grid?
  * *x*, *y*: Center location, in pixels
  * *ledSpacing*: Spacing between LEDs, in pixels
  * *stripSpacing*: Spacing between strips, in pixels
  * *angle*: Angle, in radians. Positive is clockwise. 0 has pixels in a strip going left-to-right and strips going top-to-bottom.
  * *zigzag*: true = Every other strip is reversed, false = All strips are non-reversed
 
----

* **opc.ledGrid8x8**(*index*, *x*, *y*, *spacing*, *angle*, *zigzag*)
  * Convenience method for placing an 8x8 grid of LEDs on the screen
  * *index*: Number for the first LED in the grid, starting with zero
  * *x*, *y*: Center location, in pixels
  * *spacing*: Spacing between LEDs and strips, in pixels
  * *angle*: Angle, in radians. Positive is clockwise. 0 has pixels in a strip going left-to-right and strips going top-to-bottom.
  * *zigzag*: true = Every other strip is reversed, false = All strips are non-reversed
  
----

* **opc.showLocations**(*enabled*)
  * By default, the OPC client indicates pixels we're sampling for LED values by drawing small dots.
  * *enabled*: true = Draw sampling locations as small dots, false = Do not draw sampling locations
  
----

* **opc.setPixel**(*index*, *color*)
  * Sets a single LED pixel to the indicated color
  * Only useful for LEDs that were never mapped to on-screen pixels
  * **index**: The index number for this LED, starting with zero
  * **color**: A Processing color object (24-bit)

----

* *color* = **opc.getPixel**(*index*)
  * Retrieves the color stored for a single LED pixel.
  * For LEDs mapped to on-screen pixels, this returns the color we sampled on the previous frame.
  * **index**: The index number for this LED, starting with zero
  * **color**: A Processing color object (24-bit)

----

* **opc.writePixels**()
  * Send all buffered pixels to the OPC server
  * If any pixels have been mapped on-screen, this happens automatically after every draw()
  * This is only necessary for sketches that have no pixel mapping at all.

----

* **opc.setDithering**(*enabled*)
  * By default, Fadecandy controller boards use a temporal dithering algorithm to reduce "popping" artifacts and retain color purity even when brightness changes.
  * *enabled*: true = All attached Fadecandy controller boards use dithering, false = Dithering is disabled.
  
----

* **opc.setInterpolation**(*enabled*)
  * By default, Fadecandy interpolates smoothly in hardware between the frames it receives from a sketch.
  * *enabled*: true = Frame interpolation is enabled, false = No frame interpolation, new frames take effect immediately.

----

* **opc.setStatusLed**(*on*)
  * Each Fadecandy Controller has a built-in status LED. This function takes manual control over the LEDs on each attached board, setting the LED on or off.
  * By default, LEDs blink when the board receives a new data. This default functionality can be restored with **opc.statusLedAuto()**.
  * *on*: true = Status LED turns on, false = Status LED turns off

----

* **opc.statusLedAuto**()
  * Each connected Fadecandy board's status LED will go back to its default behavior, blinking any time new data is received over USB.

----

* **opc.setColorCorrection**(*gamma*, *red*, *green*, *blue*)
* **opc.setColorCorrection**(*json*)
  * Sends new color correction parameters to all attached Fadecandy controllers.
  * These parameters override the defaults from fcserver's configuration file.
  * **gamma**: Exponent for the nonlinear brightness curve. Default is 2.5
  * **red**, **green**, **blue**: Floating point brightness values for red, green, and blue channels. These can adjust both the overall brightness and the whitepoint. Defaults are 1.0. 
  * **json**: Alternatively, a raw JSON string can be supplied. This string must be in the same format as the fcserver's *color* configuration parameter.

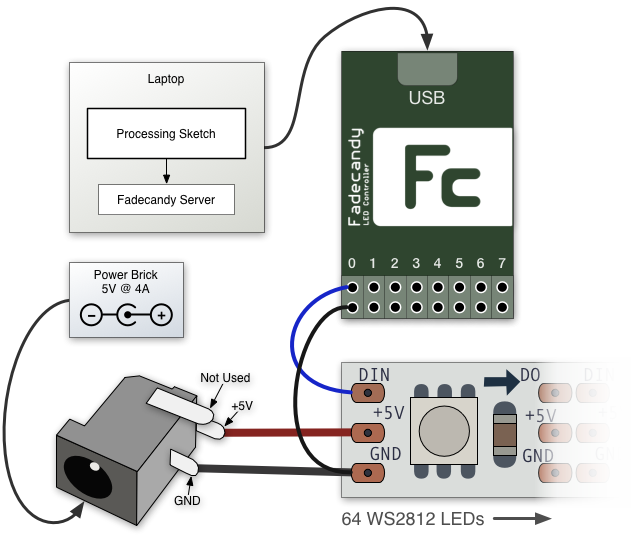
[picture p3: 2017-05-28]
doc/images/system-diagram-1.png

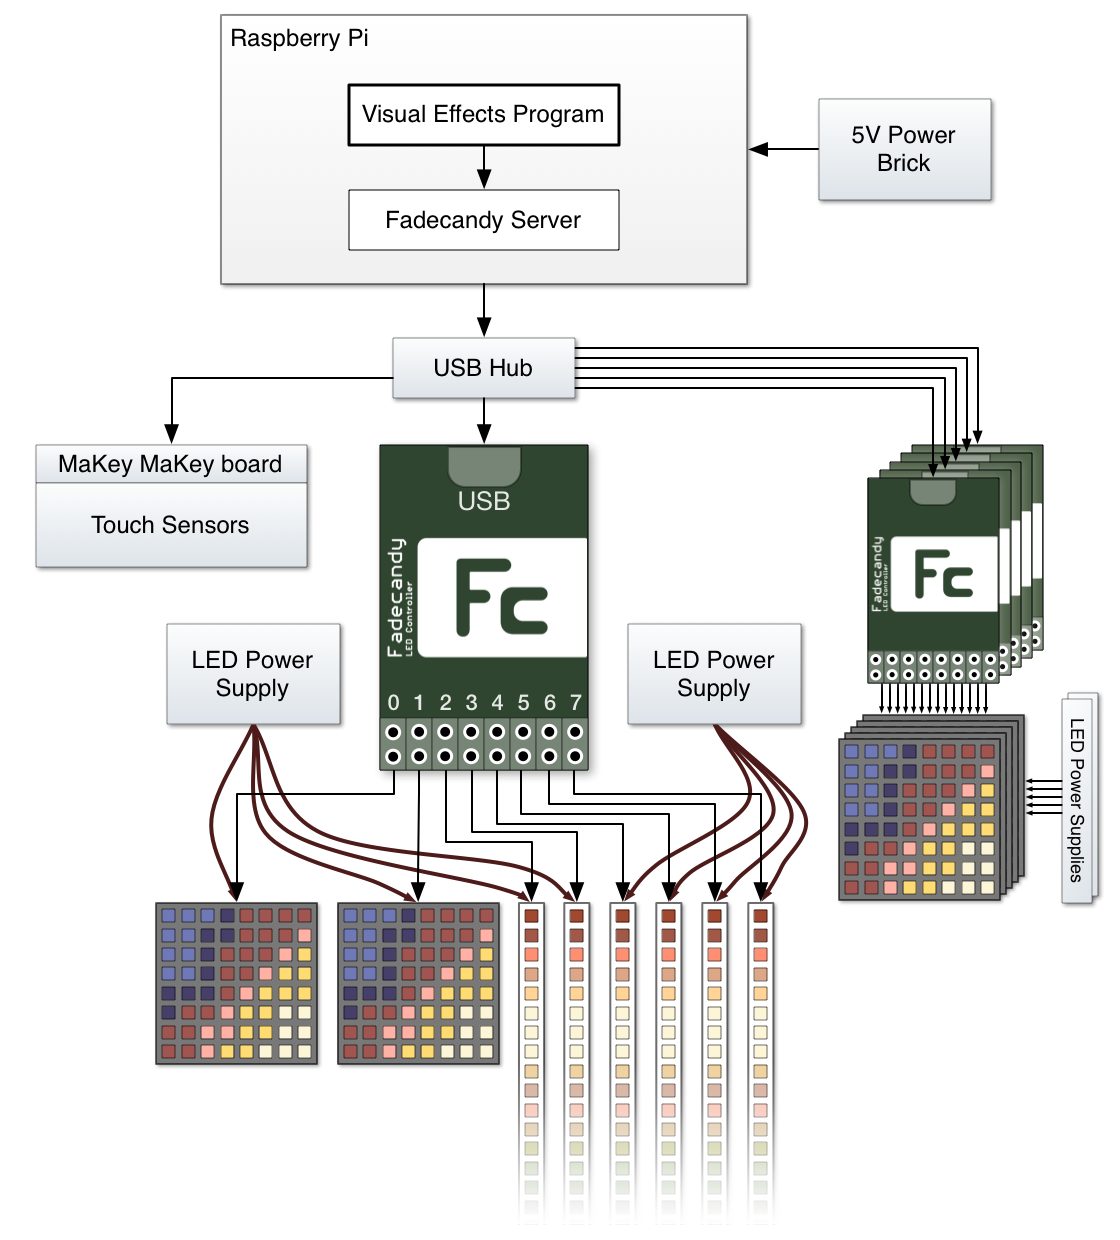
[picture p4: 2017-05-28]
doc/images/system-diagram-2@2x.png

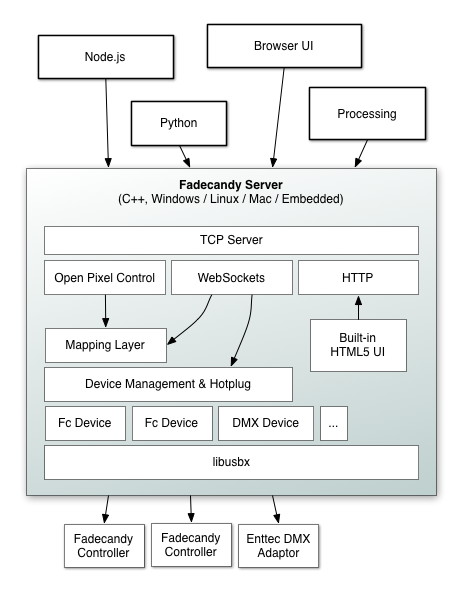
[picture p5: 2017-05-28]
doc/images/host-internals-diagram.png

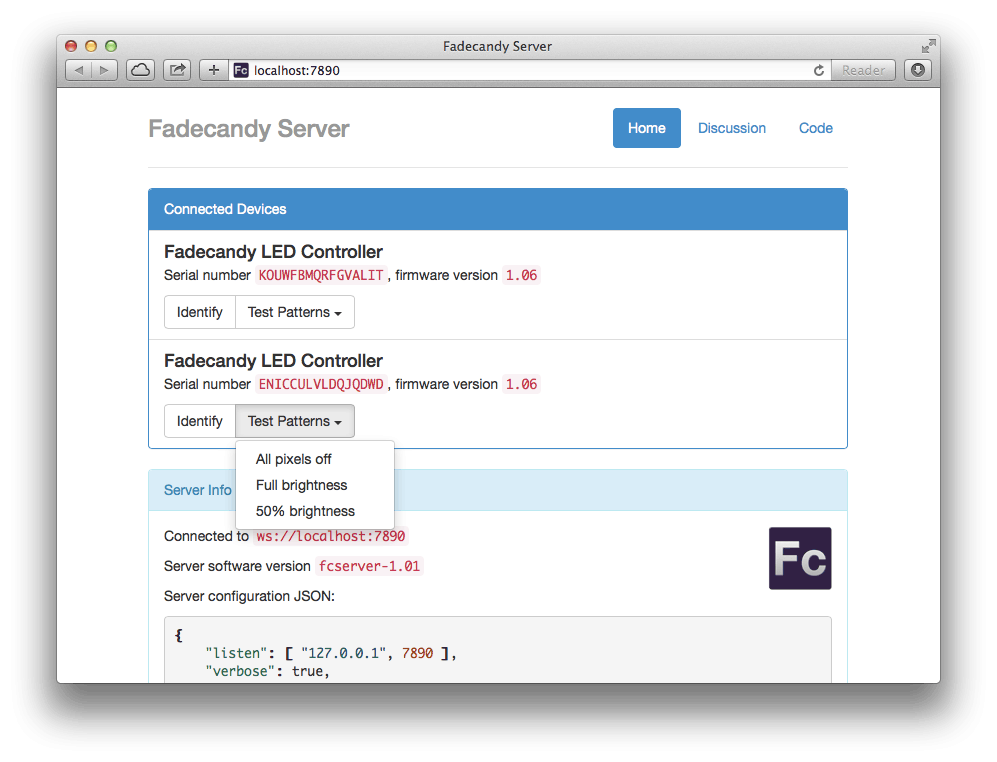
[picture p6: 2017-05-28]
doc/images/web-ui-screenshot.png

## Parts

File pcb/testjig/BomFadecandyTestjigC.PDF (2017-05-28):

## Bill Of Materials For

### Design Title

### Author

### Document Number

### Revision

Design Created | Sunday, October 13, 2013
Design Last Modified Saturday, February 22, 2014

### Total Parts In Design 36

0 Modules

Quantity | References | Value | Stock Code | Unit Cost Supplier
Sub-totals: | $0.00

4 Capacitors

Quantity | References | Value | Stock Code | Unit Cost Supplier
4 | C1-C4 | 0.1 uF
Sub-totals: | $0.00

24 Resistors

Quantity | References | Value | Stock Code | Unit Cost Supplier
10 | R1,R3,R5,R7,R9,R11,R13,R15,R17,R19 6.8K
10 | R2,R4,R6,R8,R10,R12,R14,R16,R18,R20 1K
3 | R21-R23 | 68K
1 | R29 | 3.3K
Sub-totals: | $0.00

2 Integrated Circuits

Quantity | References | Value | Stock Code | Unit Cost Supplier
1 | U2 | TEENSY3 | $19.00 | PJRC
1 | U3 | OPA350UA | OPA350UA-ND $3.30 | Digikey
Sub-totals: | $22.30

0 Transistors

Quantity | References | Value | Stock Code | Unit Cost Supplier
Sub-totals: | $0.00

2 Diodes

Quantity | References | Value | Stock Code | Unit Cost Supplier
2 | D1-D2 | WS2812B | WS2812B | $0.22
Sub-totals: | $0.44

4 Miscellaneous

Quantity | References | Value | Stock Code | Unit Cost Supplier
1 | B1 | RYBUTTON | $0.27
1 | J1 | FC HACKER
1 | J2 | CONN-DIL16
1 | USB1 | USB 4PIN
Sub-totals: | $0.27
Totals: | $23.01

Saturday, February 22, 2014 9:07:38 AM

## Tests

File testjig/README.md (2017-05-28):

Fadecandy Test Jig
==================

This is a simple one-off test fixture that's designed to facilitate in-circuit debugging of the Fadecandy firmware, and doing reliable low-volume production.

My prototype consists of:

* An ugly hand-wired perfboard
* 0.1"-spaced pogo pins which connect to the Fadecandy board's "hacker port" as well as its output header
* A standard ARM JTAG header for firmware development using an external JTAG adapter
* A 2-LED string of WS2811 LEDs, for verifying the timing of the Fadecandy outputs
* A Teensy 3.0 board which coordinates production and testing tasks

The board is intended for two separate use cases:

* During firmware development, it's a simple breakout board for the JTAG port
* During low-volume production, the Teensy installs firmware and performs electrical testing

This board is a work-in-progress. This directory contains Teensyduino sketches which run on the onboard Teensy. More information about the hardware will be included later.

Hardware tidbits
----------------

* JTAG port uses 10K pull-up resistors to Fadecandy's 3.3v rail on all signals.
* Pogo pins are 2x Digi-Key part ED8178-16-ND
* Big green button next to pogo-pins to initiate programming/test

Teensy 3.0 pin assignment
-------------------------

Pin      | Description
-------- | ----------------------------------
Gnd      | Shared ground
Vin      | +5V power for testjig itself
0        | Teensy RX, Fadecandy TX
1        | Teensy TX, Fadecandy RX
2        | To ground via green button
3        | Fadecandy TCLK (SWCLK)
4        | Fadecandy TMS (SWDIO)
5        | Fadecandy USB D- (white wire)
6        | Fadecandy USB D+ (green wire)
7        | Fadecandy USB shield ground
8        | Fadecandy USB signal ground
9        | (No connection)
10       | PWM out for power supply control
11       | DOUT of second WS2811 LED, via 3.3K current limiting resistor
12       | (No connection)
13       | (Teensy built-in LED)
14 (A0)  | Fadecandy output 0 (via resistor divider)
15 (A1)  | Fadecandy output 1 (via resistor divider)
16 (A2)  | Fadecandy output 2 (via resistor divider)
17 (A3)  | Fadecandy output 3 (via resistor divider)
18 (A4)  | Fadecandy output 4 (via resistor divider)
19 (A5)  | Fadecandy output 5 (via resistor divider)
20 (A6)  | Fadecandy output 6 (via resistor divider)
21 (A7)  | Fadecandy output 7 (via resistor divider)
22 (A8)  | Fadecandy 3.3v     (via resistor divider)
23 (A9)  | Fadecandy VUSB     (via resistor divider)

All analog inputs connect via the same resistor divider:

* 1K between analog input and ground
* 6.8K between analog input and Fadecandy signal
* Use 5% tolerance resistors or better

Target power supply (micro-USB cable) is driven at a variable voltage. This is achieved by buffering a PWM output with an RC filter and op-amp.

* Op-amp should be able to drive ~20mA. I used half an OPA2350, since it was handy.
* Op-amp supply voltage driven by Teensy VUSB (~5V), bypassed with 0.1uF cap
* Configured as a non-inverting amplifier with gain=2
  * Feedback resistor, - to out, 68K
  * Feedback resistor, - to ground, 68K
* Low-pass filter on + input
  * 68K between + and PWM input
  * 0.1uF capacitor between + and ground
* Unused op-amps configured as followers
  * 33K from - to out
  * 33K from + to ground

The Teensy isn't capable of communicating over USB with the Fadecandy board when wired this way, but the USB pins are electrically tested in a minimal way. Note that the USB signal ground and shield ground are set up this way only for electrical testing. During testing and programming, the actual power and signal ground is achieved through the test clip's connection to the output port. Except for VUSB, all signals on the USB connector are used only to electrically test the USB connector itself.

Testjig Firmwares
-----------------

* `production`
	* Programs bootloader and initial firmware image
	* Runs electrical tests
	* Communicates with the DUT processor using Serial Wire Debug
* `serial_passthrough`
	* Teensyduino sketch
    * Appears as a USB serial port device
	* Passes through access to the DUT serial port
	* When the green button is held, acts as a loopback for the DUT serial port, as one way to enter FC-Boot.

Contact
-------

Micah Elizabeth Scott <<micah@scanlime.org>>

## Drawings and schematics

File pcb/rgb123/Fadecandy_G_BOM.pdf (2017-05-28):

## Bill Of Materials For Fadecandy_G

Design Title | Fadecandy_G
Author | OHARARP LLC

### Document Number

Revision | G
Design Created | Friday, November 29, 2013
Design Last Modified Sunday, April 06, 2014

### Total Parts In Design 23

0 Modules

Quantity | References | Value | Stock Code | Unit Cost Supplier
Sub-totals: | | | | $0.00

10 Capacitors

Quantity | References | Value | Stock Code | Unit Cost Supplier
4 | C1,C5,C8,C10 10uf | 587-3383-2-ND | $0.02 | Digikey
4 | C2-C4,C11 | 0.1uf | | $0.00 | Digikey
2 | C6,C9 | 1uf | 1276-1024-2-ND | $0.01 | Digikey
Sub-totals: | | | | $0.11

3 Resistors

Quantity | References | Value | Stock Code | Unit Cost Supplier
2 | R1-R2 | 33 | 1276-5026-2-ND | $0.00 | Digikey
1 | R3 | 330 | RMCF0603JT33R0CT-ND $0.00 | Digikey
Sub-totals: | | | | $0.00

3 Integrated Circuits

Quantity | References | Value | Stock Code | Unit Cost Supplier
1 | U1 | SN74LV245ARGYR 595-SN74LV245ARGYR $0.20 | Mouser
1 | U2 | MK20DX128VLF5 | 841-MK20DX128VLF5 | $2.66 | Mouser
1 | U3 | AAT3110IGU-5 | 863-1505-1-ND | $0.26 | Digikey
Sub-totals: | | | | $3.12

0 Transistors

Quantity | References | Value | Stock Code | Unit Cost Supplier
Sub-totals: | | | | $0.00

1 Diodes

Quantity | References | Value | Stock Code | Unit Cost Supplier
1 | D1 | LED | 475-2558-1-ND | $0.09 | Digikey
Sub-totals: | | | | $0.09

3 Miscellaneous

Quantity | References | Value | Stock Code | Unit Cost Supplier
1 | RA1 | 0603 ARRAY
1 | SP | | | $0.45 | Smart Prototyping
1 | X1 | TSX-3225 16 | SER3636CT-ND | $0.35 | Digikey
Sub-totals: | | | | $0.80

3 Jumpers

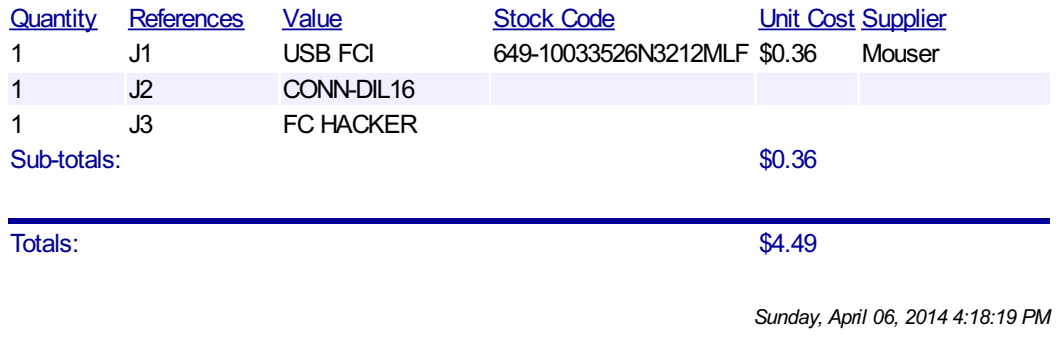
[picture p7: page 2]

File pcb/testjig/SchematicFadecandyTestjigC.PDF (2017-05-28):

U2

B1

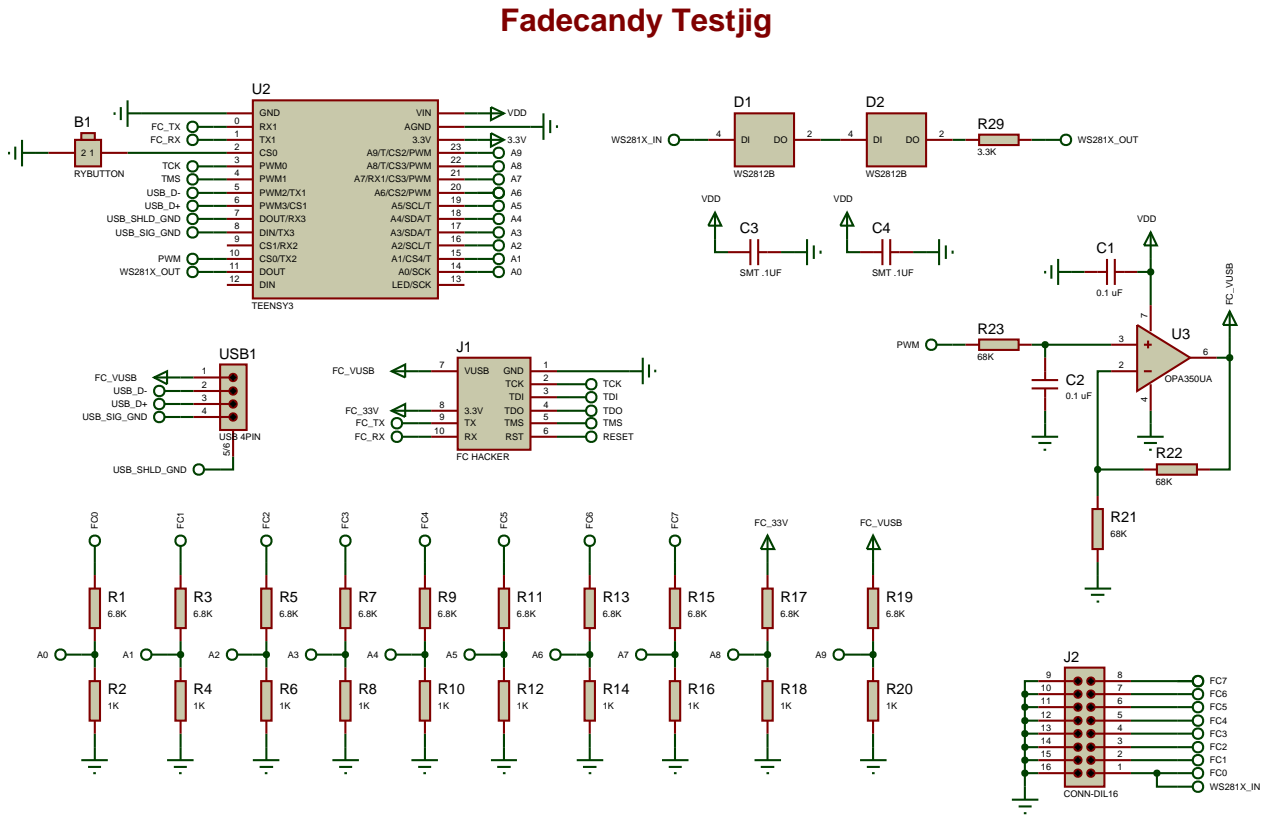
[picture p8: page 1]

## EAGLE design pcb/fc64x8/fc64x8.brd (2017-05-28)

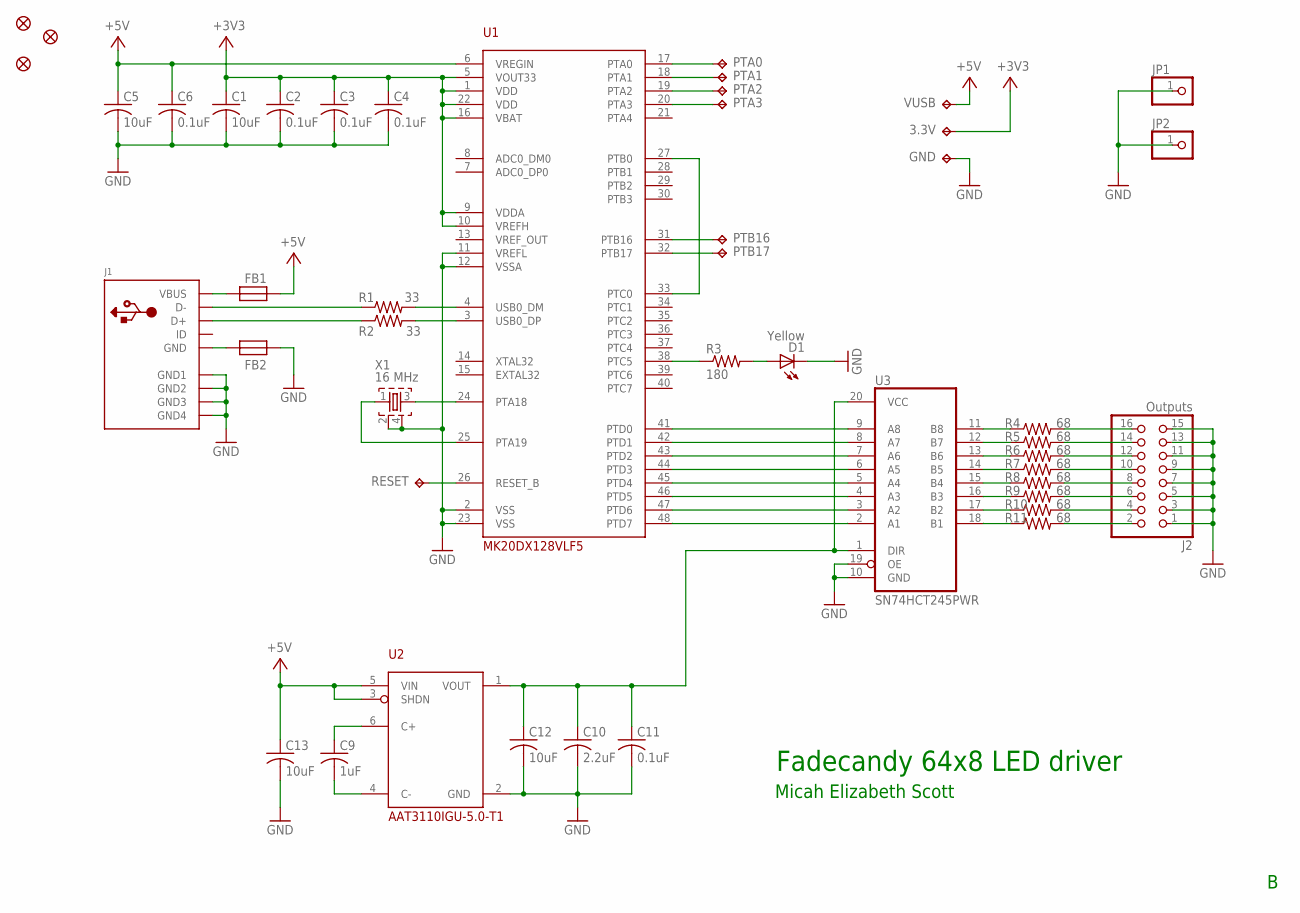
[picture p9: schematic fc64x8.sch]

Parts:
3.3V: TPTP18SQ; TP18SQ
C1, C5, C12, C13: 10uF; 0805
C2, C3, C4, C6, C11: 0.1uF; 0805
C9: 1uF; 0805
C10: 2.2uF; 0805
D1: Yellow; CHIP-LED0805
FB1, FB2: FB0805/NO-OUTLINE; 0805
FID1, FID2, FID3: FIDUCIAL""; FIDUCIAL_1MM
GND: TPTP18SQ; TP18SQ
J1: USBMINIB; USB-MINIB
J2: Outputs; 2X08
JP1, JP2: PINHD-1X1; 1X01
PTA0, PTA1, PTA2, PTA3: TPTP18SQ; TP18SQ
PTB16, PTB17: TPTP18SQ; TP18SQ
R1, R2: 33; 0805
R3: 180; 0805
R4, R5, R6, R7, R8, R9, R10, R11: 68; 0805
RESET: TPTP18SQ; TP18SQ
U1: MK20DX128VLF5; LQFP48
U2: AAT3110IGU-5.0-T1; SOT23-6L
U3: SN74HCT245PWR; TSSOP20
VUSB: TPTP18SQ; TP18SQ
X1: 16 MHz; TSX-3225

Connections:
+3V3: 3.3V.TP, C1.1, C2.1, C3.1, C4.1, U1.1 (VDD), U1.5 (VOUT33), U1.9 (VDDA), U1.10 (VREFH), U1.16 (VBAT), U1.22 (VDD)
+5V: C5.1, C6.1, C13.1, FB1.2, U1.6 (VREGIN), U2.3 (SHDN), U2.5 (VIN), VUSB.TP
GND: C1.2, C2.2, C3.2, C4.2, C5.2, C6.2, C10.2, C11.2, C12.2, C13.2, D1.C, FB2.2, GND.TP, J1.GND1, J1.GND2, J1.GND3, J1.GND4, J2.1, J2.3, J2.5, J2.7, J2.9, J2.11, J2.13, J2.15, JP1.1, JP2.1, U1.2 (VSS), U1.11 (VREFL), U1.12 (VSSA), U1.23 (VSS), U2.2 (GND), U3.10 (GND), U3.19 (OE), X1.2, X1.4
unnamed: R3.1, U1.38 (PTC5)
unnamed: U1.24 (PTA18), X1.3
unnamed: D1.A, R3.2
unnamed: U1.25 (PTA19), X1.1
unnamed: FB1.1, J1.VBUS
unnamed: U1.27 (PTB0), U1.33 (PTC0)
unnamed: FB2.1, J1.GND
unnamed: U1.41 (PTD0), U3.9 (A8)
unnamed: J1.D-, R1.1
unnamed: J1.D+, R2.1
unnamed: R1.2, U1.4 (USB0_DM)
unnamed: R2.2, U1.3 (USB0_DP)
unnamed: U1.42 (PTD1), U3.8 (A7)
unnamed: U1.43 (PTD2), U3.7 (A6)
unnamed: U1.44 (PTD3), U3.6 (A5)
unnamed: U1.45 (PTD4), U3.5 (A4)
unnamed: U1.46 (PTD5), U3.4 (A3)
unnamed: U1.47 (PTD6), U3.3 (A2)
unnamed: U1.48 (PTD7), U3.2 (A1)
unnamed: R4.1, U3.11 (B8)
unnamed: C9.1, U2.6 (C+)
unnamed: C9.2, U2.4 (C-)
unnamed: R5.1, U3.12 (B7)
unnamed: R6.1, U3.13 (B6)
unnamed: R7.1, U3.14 (B5)
unnamed: R8.1, U3.15 (B4)
unnamed: C10.1, C11.1, C12.1, U2.1 (VOUT), U3.1 (DIR), U3.20 (VCC)
unnamed: R9.1, U3.16 (B3)
unnamed: R10.1, U3.17 (B2)
unnamed: R11.1, U3.18 (B1)
unnamed: J2.16, R4.2
unnamed: J2.14, R5.2
unnamed: J2.12, R6.2
unnamed: J2.10, R7.2
unnamed: J2.8, R8.2
unnamed: J2.6, R9.2
unnamed: J2.4, R10.2
unnamed: J2.2, R11.2
unnamed: RESET.TP, U1.26 (RESET_B)
unnamed: PTA0.TP, U1.17 (PTA0)
unnamed: PTA1.TP, U1.18 (PTA1)
unnamed: PTA2.TP, U1.19 (PTA2)
unnamed: PTA3.TP, U1.20 (PTA3)
unnamed: PTB16.TP, U1.31 (PTB16)
unnamed: PTB17.TP, U1.32 (PTB17)

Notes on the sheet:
Fadecandy 64x8 LED driver
Micah Elizabeth Scott

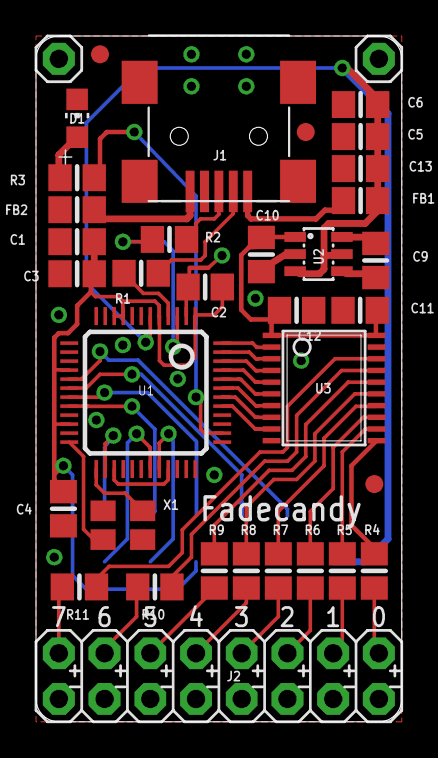
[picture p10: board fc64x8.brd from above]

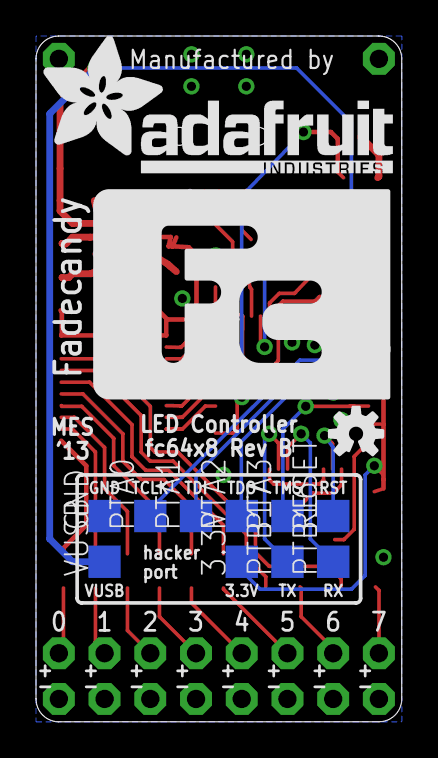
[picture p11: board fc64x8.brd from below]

Board: 2 copper layers, 20.3 x 38.1 mm, 48 parts (12 on the bottom side), 48 nets.

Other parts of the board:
U$1: OSHW-LOGO-S
U$2: ADAFRUIT_TEXT_20MM

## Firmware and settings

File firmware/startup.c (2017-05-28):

/*
 * Initialization code for an FC-Boot application.
 * Copyright (c) 2013 Micah Elizabeth Scott
 *
 * Originally based on:
 *
 * Teensyduino Core Library
 * http://www.pjrc.com/teensy/
 * Copyright (c) 2013 PJRC.COM, LLC.
 *
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
 * 2. If the Software is incorporated into a build system that allows 
 * selection among a list of target devices, then similar target
 * devices manufactured by PJRC.COM must be included in the list of
 * target devices and selectable in the same manner.
 *
 * THE SOFTWARE IS PROVIDED "AS IS", WITHOUT WARRANTY OF ANY KIND,
 * EXPRESS OR IMPLIED, INCLUDING BUT NOT LIMITED TO THE WARRANTIES OF
 * MERCHANTABILITY, FITNESS FOR A PARTICULAR PURPOSE AND
 * NONINFRINGEMENT. IN NO EVENT SHALL THE AUTHORS OR COPYRIGHT HOLDERS
 * BE LIABLE FOR ANY CLAIM, DAMAGES OR OTHER LIABILITY, WHETHER IN AN
 * ACTION OF CONTRACT, TORT OR OTHERWISE, ARISING FROM, OUT OF OR IN
 * CONNECTION WITH THE SOFTWARE OR THE USE OR OTHER DEALINGS IN THE
 * SOFTWARE.
 */

#include "mk20dx128.h"

typedef void (*initFunc_t)(void);

extern unsigned long _stext;
extern unsigned long _etext;
extern unsigned long _sdata;
extern unsigned long _edata;
extern unsigned long _sbss;
extern unsigned long _ebss;
extern unsigned long _estack;
extern unsigned long _flexram_begin;
extern unsigned long _flexram_end;
extern initFunc_t __init_array_start;
extern initFunc_t __init_array_end;

extern int main (void);
void ResetHandler(void);
void _init_Teensyduino_internal_(void);


void fault_isr(void)
{
        while (1); // die
}

void unused_isr(void)
{
        while (1); // die
}

extern volatile uint32_t systick_millis_count;
void systick_default_isr(void)
{
    systick_millis_count++;
}

void nmi_isr(void)      __attribute__ ((weak, alias("unused_isr")));
void hard_fault_isr(void)   __attribute__ ((weak, alias("unused_isr")));
void memmanage_fault_isr(void)  __attribute__ ((weak, alias("unused_isr")));
void bus_fault_isr(void)    __attribute__ ((weak, alias("unused_isr")));
void usage_fault_isr(void)  __attribute__ ((weak, alias("unused_isr")));
void svcall_isr(void)       __attribute__ ((weak, alias("unused_isr")));
void debugmonitor_isr(void) __attribute__ ((weak, alias("unused_isr")));
void pendablesrvreq_isr(void)   __attribute__ ((weak, alias("unused_isr")));
void systick_isr(void)      __attribute__ ((weak, alias("systick_default_isr")));

void dma_ch0_isr(void)      __attribute__ ((weak, alias("unused_isr")));
void dma_ch1_isr(void)      __attribute__ ((weak, alias("unused_isr")));
void dma_ch2_isr(void)      __attribute__ ((weak, alias("unused_isr")));
void dma_ch3_isr(void)      __attribute__ ((weak, alias("unused_isr")));
void dma_error_isr(void)    __attribute__ ((weak, alias("unused_isr")));
void flash_cmd_isr(void)    __attribute__ ((weak, alias("unused_isr")));
void flash_error_isr(void)  __attribute__ ((weak, alias("unused_isr")));
void low_voltage_isr(void)  __attribute__ ((weak, alias("unused_isr")));
void wakeup_isr(void)       __attribute__ ((weak, alias("unused_isr")));
void watchdog_isr(void)     __attribute__ ((weak, alias("unused_isr")));
void i2c0_isr(void)     __attribute__ ((weak, alias("unused_isr")));
void spi0_isr(void)     __attribute__ ((weak, alias("unused_isr")));
void i2s0_tx_isr(void)      __attribute__ ((weak, alias("unused_isr")));
void i2s0_rx_isr(void)      __attribute__ ((weak, alias("unused_isr")));
void uart0_lon_isr(void)    __attribute__ ((weak, alias("unused_isr")));
void uart0_status_isr(void) __attribute__ ((weak, alias("unused_isr")));
void uart0_error_isr(void)  __attribute__ ((weak, alias("unused_isr")));
void uart1_status_isr(void) __attribute__ ((weak, alias("unused_isr")));
void uart1_error_isr(void)  __attribute__ ((weak, alias("unused_isr")));
void uart2_status_isr(void) __attribute__ ((weak, alias("unused_isr")));
void uart2_error_isr(void)  __attribute__ ((weak, alias("unused_isr")));
void adc0_isr(void)     __attribute__ ((weak, alias("unused_isr")));
void cmp0_isr(void)     __attribute__ ((weak, alias("unused_isr")));
void cmp1_isr(void)     __attribute__ ((weak, alias("unused_isr")));
void ftm0_isr(void)     __attribute__ ((weak, alias("unused_isr")));
void ftm1_isr(void)     __attribute__ ((weak, alias("unused_isr")));
void cmt_isr(void)      __attribute__ ((weak, alias("unused_isr")));
void rtc_alarm_isr(void)    __attribute__ ((weak, alias("unused_isr")));
void rtc_seconds_isr(void)  __attribute__ ((weak, alias("unused_isr")));
void pit0_isr(void)     __attribute__ ((weak, alias("unused_isr")));
void pit1_isr(void)     __attribute__ ((weak, alias("unused_isr")));
void pit2_isr(void)     __attribute__ ((weak, alias("unused_isr")));
void pit3_isr(void)     __attribute__ ((weak, alias("unused_isr")));
void pdb_isr(void)      __attribute__ ((weak, alias("unused_isr")));
void usb_isr(void)      __attribute__ ((weak, alias("unused_isr")));
void usb_charge_isr(void)   __attribute__ ((weak, alias("unused_isr")));
void tsi0_isr(void)     __attribute__ ((weak, alias("unused_isr")));
void mcg_isr(void)      __attribute__ ((weak, alias("unused_isr")));
void lptmr_isr(void)        __attribute__ ((weak, alias("unused_isr")));
void porta_isr(void)        __attribute__ ((weak, alias("unused_isr")));
void portb_isr(void)        __attribute__ ((weak, alias("unused_isr")));
void portc_isr(void)        __attribute__ ((weak, alias("unused_isr")));
void portd_isr(void)        __attribute__ ((weak, alias("unused_isr")));
void porte_isr(void)        __attribute__ ((weak, alias("unused_isr")));
void software_isr(void)     __attribute__ ((weak, alias("unused_isr")));


// TODO: create AVR-stype ISR() macro, with default linkage to undefined handler
//
__attribute__ ((section(".vectors"), used))
void (* const gVectors[])(void) =
{
        (void (*)(void))((unsigned long)&_estack),  //  0 ARM: Initial Stack Pointer
        ResetHandler,                   //  1 ARM: Initial Program Counter
    nmi_isr,                    //  2 ARM: Non-maskable Interrupt (NMI)
    hard_fault_isr,                 //  3 ARM: Hard Fault
    memmanage_fault_isr,                //  4 ARM: MemManage Fault
    bus_fault_isr,                  //  5 ARM: Bus Fault
    usage_fault_isr,                //  6 ARM: Usage Fault
    fault_isr,                  //  7 --
    fault_isr,                  //  8 --
    fault_isr,                  //  9 --
    fault_isr,                  // 10 --
    svcall_isr,                 // 11 ARM: Supervisor call (SVCall)
    debugmonitor_isr,               // 12 ARM: Debug Monitor
    fault_isr,                  // 13 --
    pendablesrvreq_isr,             // 14 ARM: Pendable req serv(PendableSrvReq)
    systick_isr,                    // 15 ARM: System tick timer (SysTick)
    dma_ch0_isr,                    // 16 DMA channel 0 transfer complete
    dma_ch1_isr,                    // 17 DMA channel 1 transfer complete
    dma_ch2_isr,                    // 18 DMA channel 2 transfer complete
    dma_ch3_isr,                    // 19 DMA channel 3 transfer complete
    dma_error_isr,                  // 20 DMA error interrupt channel
    unused_isr,                 // 21 DMA --
    flash_cmd_isr,                  // 22 Flash Memory Command complete
    flash_error_isr,                // 23 Flash Read collision
    low_voltage_isr,                // 24 Low-voltage detect/warning
    wakeup_isr,                 // 25 Low Leakage Wakeup
    watchdog_isr,                   // 26 Both EWM and WDOG interrupt
    i2c0_isr,                   // 27 I2C0
    spi0_isr,                   // 28 SPI0
    i2s0_tx_isr,                    // 29 I2S0 Transmit
    i2s0_rx_isr,                    // 30 I2S0 Receive
    uart0_lon_isr,                  // 31 UART0 CEA709.1-B (LON) status
    uart0_status_isr,               // 32 UART0 status
    uart0_error_isr,                // 33 UART0 error
    uart1_status_isr,               // 34 UART1 status
    uart1_error_isr,                // 35 UART1 error
    uart2_status_isr,               // 36 UART2 status
    uart2_error_isr,                // 37 UART2 error
    adc0_isr,                   // 38 ADC0
    cmp0_isr,                   // 39 CMP0
    cmp1_isr,                   // 40 CMP1
    ftm0_isr,                   // 41 FTM0
    ftm1_isr,                   // 42 FTM1
    cmt_isr,                    // 43 CMT
    rtc_alarm_isr,                  // 44 RTC Alarm interrupt
    rtc_seconds_isr,                // 45 RTC Seconds interrupt
    pit0_isr,                   // 46 PIT Channel 0
    pit1_isr,                   // 47 PIT Channel 1
    pit2_isr,                   // 48 PIT Channel 2
    pit3_isr,                   // 49 PIT Channel 3
    pdb_isr,                    // 50 PDB Programmable Delay Block
    usb_isr,                    // 51 USB OTG
    usb_charge_isr,                 // 52 USB Charger Detect
    tsi0_isr,                   // 53 TSI0
    mcg_isr,                    // 54 MCG
    lptmr_isr,                  // 55 Low Power Timer
    porta_isr,                  // 56 Pin detect (Port A)
    portb_isr,                  // 57 Pin detect (Port B)
    portc_isr,                  // 58 Pin detect (Port C)
    portd_isr,                  // 59 Pin detect (Port D)
    porte_isr,                  // 60 Pin detect (Port E)
    software_isr,                   // 61 Software interrupt
};

static unsigned ftfl_busy()
{
    // Is the flash memory controller busy?
    return 0 == (FTFL_FSTAT_CCIF & FTFL_FSTAT);
}

static void ftfl_busy_wait()
{
    // Wait for the flash memory controller to finish any pending operation.
    while (ftfl_busy());
}

static void ftfl_launch_command()
{
    // Begin a flash memory controller command
    FTFL_FSTAT = FTFL_FSTAT_ACCERR | FTFL_FSTAT_FPVIOL | FTFL_FSTAT_RDCOLERR;
    FTFL_FSTAT = FTFL_FSTAT_CCIF;
}

static void ftfl_set_flexram_function(uint8_t control_code)
{
    // Issue a Set FlexRAM Function command. Busy-waits until the command is done.
    
    ftfl_busy_wait();
    FTFL_FCCOB0 = 0x81;
    FTFL_FCCOB1 = control_code;
    ftfl_launch_command();
    ftfl_busy_wait();
}

void ResetHandler(void)
{
    // Init data RAM
    uint32_t *src = &_etext;
    uint32_t *dest = &_sdata;
    while (dest < &_edata) *dest++ = *src++;
    dest = &_sbss;
    while (dest < &_ebss) *dest++ = 0;

    // initialize the SysTick counter
    SYST_RVR = (F_CPU / 1000) - 1;
    SYST_CSR = SYST_CSR_CLKSOURCE | SYST_CSR_TICKINT | SYST_CSR_ENABLE;

    // Use FlexRAM as normal RAM, and zero it
    ftfl_set_flexram_function(0xFF);
    dest = &_flexram_begin;
    while (dest < &_flexram_end) *dest++ = 0;

    __enable_irq();
    _init_Teensyduino_internal_();

    initFunc_t *p = &__init_array_start;
    for (; p != &__init_array_end; p++)
        p[0]();

    main();
    while (1) ;
}

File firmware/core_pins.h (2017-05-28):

/* Teensyduino Core Library
 * http://www.pjrc.com/teensy/
 * Copyright (c) 2013 PJRC.COM, LLC.
 *
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
 * 2. If the Software is incorporated into a build system that allows 
 * selection among a list of target devices, then similar target
 * devices manufactured by PJRC.COM must be included in the list of
 * target devices and selectable in the same manner.
 *
 * THE SOFTWARE IS PROVIDED "AS IS", WITHOUT WARRANTY OF ANY KIND,
 * EXPRESS OR IMPLIED, INCLUDING BUT NOT LIMITED TO THE WARRANTIES OF
 * MERCHANTABILITY, FITNESS FOR A PARTICULAR PURPOSE AND
 * NONINFRINGEMENT. IN NO EVENT SHALL THE AUTHORS OR COPYRIGHT HOLDERS
 * BE LIABLE FOR ANY CLAIM, DAMAGES OR OTHER LIABILITY, WHETHER IN AN
 * ACTION OF CONTRACT, TORT OR OTHERWISE, ARISING FROM, OUT OF OR IN
 * CONNECTION WITH THE SOFTWARE OR THE USE OR OTHER DEALINGS IN THE
 * SOFTWARE.
 */

#ifndef _core_pins_h_
#define _core_pins_h_

#include "mk20dx128.h"
#include "pins_arduino.h"


#define HIGH        1
#define LOW     0
#define INPUT       0
#define OUTPUT      1
#define INPUT_PULLUP    2
#define LSBFIRST    0
#define MSBFIRST    1
#define _BV(n)      (1<<(n))
#define CHANGE      4
#define FALLING     2
#define RISING      3

// Pin              Arduino
//  0   B16         RXD
//  1   B17         TXD
//  2   D0          
//  3   A12 FTM1_CH0    
//  4   A13 FTM1_CH1    
//  5   D7  FTM0_CH7    OC0B/T1
//  6   D4  FTM0_CH4    OC0A
//  7   D2          
//  8   D3          ICP1
//  9   C3  FTM0_CH2    OC1A
// 10   C4  FTM0_CH3    SS/OC1B
// 11   C6          MOSI/OC2A
// 12   C7          MISO
// 13   C5          SCK 
// 14   D1          
// 15   C0          
// 16   B0  (FTM1_CH0)  
// 17   B1  (FTM1_CH1)  
// 18   B3          SDA
// 19   B2          SCL
// 20   D5  FTM0_CH5    
// 21   D6  FTM0_CH6    
// 22   C1  FTM0_CH0    
// 23   C2  FTM0_CH1    
// 24   A5  (FTM0_CH2)  
// 25   B19
// 26   E1
// 27   C9
// 28   C8
// 29   C10
// 30   C11
// 31   E0
// 32   B18
// 33   A4  (FTM0_CH1)
// (34) analog only
// (35) analog only
// (36) analog only
// (37) analog only

// not available to user:
//  A0  FTM0_CH5    SWD Clock
//  A1  FTM0_CH6    USB ID
//  A2  FTM0_CH7    SWD Trace
//  A3  FTM0_CH0    SWD Data

#define CORE_NUM_TOTAL_PINS     34
#define CORE_NUM_DIGITAL        34
#define CORE_NUM_ANALOG         14
#define CORE_NUM_PWM            10
#define CORE_NUM_INTERRUPT      34

#define CORE_PIN0_BIT       16
#define CORE_PIN1_BIT       17
#define CORE_PIN2_BIT       0
#define CORE_PIN3_BIT       12
#define CORE_PIN4_BIT       13
#define CORE_PIN5_BIT       7
#define CORE_PIN6_BIT       4
#define CORE_PIN7_BIT       2
#define CORE_PIN8_BIT       3
#define CORE_PIN9_BIT       3
#define CORE_PIN10_BIT      4
#define CORE_PIN11_BIT      6
#define CORE_PIN12_BIT      7
#define CORE_PIN13_BIT      5
#define CORE_PIN14_BIT      1
#define CORE_PIN15_BIT      0
#define CORE_PIN16_BIT      0
#define CORE_PIN17_BIT      1
#define CORE_PIN18_BIT      3
#define CORE_PIN19_BIT      2
#define CORE_PIN20_BIT      5
#define CORE_PIN21_BIT      6
#define CORE_PIN22_BIT      1
#define CORE_PIN23_BIT      2
#define CORE_PIN24_BIT      5
#define CORE_PIN25_BIT      19
#define CORE_PIN26_BIT      1
#define CORE_PIN27_BIT      9
#define CORE_PIN28_BIT      8
#define CORE_PIN29_BIT      10
#define CORE_PIN30_BIT      11
#define CORE_PIN31_BIT      0
#define CORE_PIN32_BIT      18
#define CORE_PIN33_BIT      4
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

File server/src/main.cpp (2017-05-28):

/*
 * Open Pixel Control server for Fadecandy
 * 
 * Copyright (c) 2013 Micah Elizabeth Scott
 * 
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
 * THE SOFTWARE IS PROVIDED "AS IS", WITHOUT WARRANTY OF ANY KIND, EXPRESS OR
 * IMPLIED, INCLUDING BUT NOT LIMITED TO THE WARRANTIES OF MERCHANTABILITY, FITNESS
 * FOR A PARTICULAR PURPOSE AND NONINFRINGEMENT. IN NO EVENT SHALL THE AUTHORS OR
 * COPYRIGHT HOLDERS BE LIABLE FOR ANY CLAIM, DAMAGES OR OTHER LIABILITY, WHETHER
 * IN AN ACTION OF CONTRACT, TORT OR OTHERWISE, ARISING FROM, OUT OF OR IN
 * CONNECTION WITH THE SOFTWARE OR THE USE OR OTHER DEALINGS IN THE SOFTWARE.
 */

#include "rapidjson/document.h"
#include "rapidjson/reader.h"
#include "rapidjson/filestream.h"
#include "fcserver.h"
#include "version.h"
#include <cstdio>
#include <iostream>

const char *kDefaultConfig =
    "    {\n"
    "        \"listen\": [\"127.0.0.1\", 7890],\n"
    "        \"verbose\": true,\n"
    "    \n"
    "        \"color\": {\n"
    "            \"gamma\": 2.5,\n"
    "            \"whitepoint\": [1.0, 1.0, 1.0]\n"
    "        },\n"
    "    \n"
    "        \"devices\": [\n"
    "            {\n"
    "                \"type\": \"fadecandy\",\n"
    "                \"map\": [[ 0, 0, 0, 512 ]]\n"
    "            }\n"
    "        ]\n"
    "    }\n";


int main(int argc, char **argv)
{
    rapidjson::Document config;

    libusb_context *usb;
    if (libusb_init(&usb)) {
        std::clog << "Error initializing USB library!\n";
        return 7;
    }

    if (argc == 2 && argv[1][0] != '-') {
        // Load config from file

        FILE *configFile = fopen(argv[1], "r");
        if (!configFile) {
            perror("Error opening config file");
            return 2;
        }

        rapidjson::FileStream istr(configFile);
        config.ParseStream<0>(istr);

    } else if (argc == 1) {
        // Load default configuration

        config.Parse<0>(kDefaultConfig);

    } else {
        // Unknown, show usage message.

        fprintf(stderr,
            "\n"
            "Fadecandy Open Pixel Control server\n"
            "%s\n"
            "\n"
            "usage: fcserver [<config.json>]\n"
            "\n"
            "To use multiple Fadecandy devices or to set up a custom\n"
            "mapping from OPC pixel to Fadecandy pixel, you can provide\n"
            "a JSON configuration file. By default, all detected Fadecandy\n"
            "boards map directly to OPC pixels using the following default\n"
            "configuration. For more information about the config file\n"
            "format, see the README.\n"
            "\n"
            "%s"
            "\n"
            "Copyright (c) 2013 Micah Elizabeth Scott <micah@scanlime.org>\n"
            "https://github.com/scanlime/fadecandy\n"
            "\n"
            "Portions of this software are licensed under the GNU General\n"
            "Public License. Full license information and source code are\n"
            "available at the URL above.\n"
            "\n",
            kFCServerVersion,
            kDefaultConfig);
        return 1;
    }

    if (config.HasParseError()) {
        fprintf(stderr, "Parse error at character %d: %s\n",
            int(config.GetErrorOffset()), config.GetParseError());
        return 3;
    }

    FCServer server(config);
    if (server.hasError()) {
        fprintf(stderr, "Configuration errors:\n%s", server.errorText());
        return 5;
    }
    if (!server.start(usb)) {
        return 9;
    }

    server.mainLoop();

    // If mainLoop() exits, it was an error
    return 8;
}

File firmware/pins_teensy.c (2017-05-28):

/* Teensyduino Core Library
 * http://www.pjrc.com/teensy/
 * Copyright (c) 2013 PJRC.COM, LLC.
 *
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
 * 2. If the Software is incorporated into a build system that allows 
 * selection among a list of target devices, then similar target
 * devices manufactured by PJRC.COM must be included in the list of
 * target devices and selectable in the same manner.
 *
 * THE SOFTWARE IS PROVIDED "AS IS", WITHOUT WARRANTY OF ANY KIND,
 * EXPRESS OR IMPLIED, INCLUDING BUT NOT LIMITED TO THE WARRANTIES OF
 * MERCHANTABILITY, FITNESS FOR A PARTICULAR PURPOSE AND
 * NONINFRINGEMENT. IN NO EVENT SHALL THE AUTHORS OR COPYRIGHT HOLDERS
 * BE LIABLE FOR ANY CLAIM, DAMAGES OR OTHER LIABILITY, WHETHER IN AN
 * ACTION OF CONTRACT, TORT OR OTHERWISE, ARISING FROM, OUT OF OR IN
 * CONNECTION WITH THE SOFTWARE OR THE USE OR OTHER DEALINGS IN THE
 * SOFTWARE.
 */

#include "core_pins.h"
#include "pins_arduino.h"

#define GPIO_BITBAND_ADDR(reg, bit) (((uint32_t)&(reg) - 0x40000000) * 32 + (bit) * 4 + 0x42000000)
#define GPIO_BITBAND_PTR(reg, bit) ((uint32_t *)GPIO_BITBAND_ADDR((reg), (bit)))
//#define GPIO_SET_BIT(reg, bit) (*GPIO_BITBAND_PTR((reg), (bit)) = 1)
//#define GPIO_CLR_BIT(reg, bit) (*GPIO_BITBAND_PTR((reg), (bit)) = 0)

const struct digital_pin_bitband_and_config_table_struct digital_pin_to_info_PGM[] = {
    {GPIO_BITBAND_PTR(CORE_PIN0_PORTREG, CORE_PIN0_BIT), &CORE_PIN0_CONFIG},
    {GPIO_BITBAND_PTR(CORE_PIN1_PORTREG, CORE_PIN1_BIT), &CORE_PIN1_CONFIG},
    {GPIO_BITBAND_PTR(CORE_PIN2_PORTREG, CORE_PIN2_BIT), &CORE_PIN2_CONFIG},
    {GPIO_BITBAND_PTR(CORE_PIN3_PORTREG, CORE_PIN3_BIT), &CORE_PIN3_CONFIG},
    {GPIO_BITBAND_PTR(CORE_PIN4_PORTREG, CORE_PIN4_BIT), &CORE_PIN4_CONFIG},
    {GPIO_BITBAND_PTR(CORE_PIN5_PORTREG, CORE_PIN5_BIT), &CORE_PIN5_CONFIG},
    {GPIO_BITBAND_PTR(CORE_PIN6_PORTREG, CORE_PIN6_BIT), &CORE_PIN6_CONFIG},
    {GPIO_BITBAND_PTR(CORE_PIN7_PORTREG, CORE_PIN7_BIT), &CORE_PIN7_CONFIG},
    {GPIO_BITBAND_PTR(CORE_PIN8_PORTREG, CORE_PIN8_BIT), &CORE_PIN8_CONFIG},
    {GPIO_BITBAND_PTR(CORE_PIN9_PORTREG, CORE_PIN9_BIT), &CORE_PIN9_CONFIG},
    {GPIO_BITBAND_PTR(CORE_PIN10_PORTREG, CORE_PIN10_BIT), &CORE_PIN10_CONFIG},
    {GPIO_BITBAND_PTR(CORE_PIN11_PORTREG, CORE_PIN11_BIT), &CORE_PIN11_CONFIG},
    {GPIO_BITBAND_PTR(CORE_PIN12_PORTREG, CORE_PIN12_BIT), &CORE_PIN12_CONFIG},
    {GPIO_BITBAND_PTR(CORE_PIN13_PORTREG, CORE_PIN13_BIT), &CORE_PIN13_CONFIG},
    {GPIO_BITBAND_PTR(CORE_PIN14_PORTREG, CORE_PIN14_BIT), &CORE_PIN14_CONFIG},
    {GPIO_BITBAND_PTR(CORE_PIN15_PORTREG, CORE_PIN15_BIT), &CORE_PIN15_CONFIG},
    {GPIO_BITBAND_PTR(CORE_PIN16_PORTREG, CORE_PIN16_BIT), &CORE_PIN16_CONFIG},
    {GPIO_BITBAND_PTR(CORE_PIN17_PORTREG, CORE_PIN17_BIT), &CORE_PIN17_CONFIG},
    {GPIO_BITBAND_PTR(CORE_PIN18_PORTREG, CORE_PIN18_BIT), &CORE_PIN18_CONFIG},
    {GPIO_BITBAND_PTR(CORE_PIN19_PORTREG, CORE_PIN19_BIT), &CORE_PIN19_CONFIG},
    {GPIO_BITBAND_PTR(CORE_PIN20_PORTREG, CORE_PIN20_BIT), &CORE_PIN20_CONFIG},
    {GPIO_BITBAND_PTR(CORE_PIN21_PORTREG, CORE_PIN21_BIT), &CORE_PIN21_CONFIG},
    {GPIO_BITBAND_PTR(CORE_PIN22_PORTREG, CORE_PIN22_BIT), &CORE_PIN22_CONFIG},
    {GPIO_BITBAND_PTR(CORE_PIN23_PORTREG, CORE_PIN23_BIT), &CORE_PIN23_CONFIG},
    {GPIO_BITBAND_PTR(CORE_PIN24_PORTREG, CORE_PIN24_BIT), &CORE_PIN24_CONFIG},
    {GPIO_BITBAND_PTR(CORE_PIN25_PORTREG, CORE_PIN25_BIT), &CORE_PIN25_CONFIG},
    {GPIO_BITBAND_PTR(CORE_PIN26_PORTREG, CORE_PIN26_BIT), &CORE_PIN26_CONFIG},
    {GPIO_BITBAND_PTR(CORE_PIN27_PORTREG, CORE_PIN27_BIT), &CORE_PIN27_CONFIG},
    {GPIO_BITBAND_PTR(CORE_PIN28_PORTREG, CORE_PIN28_BIT), &CORE_PIN28_CONFIG},
    {GPIO_BITBAND_PTR(CORE_PIN29_PORTREG, CORE_PIN29_BIT), &CORE_PIN29_CONFIG},
    {GPIO_BITBAND_PTR(CORE_PIN30_PORTREG, CORE_PIN30_BIT), &CORE_PIN30_CONFIG},
    {GPIO_BITBAND_PTR(CORE_PIN31_PORTREG, CORE_PIN31_BIT), &CORE_PIN31_CONFIG},
    {GPIO_BITBAND_PTR(CORE_PIN32_PORTREG, CORE_PIN32_BIT), &CORE_PIN32_CONFIG},
    {GPIO_BITBAND_PTR(CORE_PIN33_PORTREG, CORE_PIN33_BIT), &CORE_PIN33_CONFIG}
};

unsigned long rtc_get(void)
{
    return RTC_TSR;
}

void rtc_set(unsigned long t)
{
    RTC_SR = 0;
    RTC_TPR = 0;
    RTC_TSR = t;
    RTC_SR = RTC_SR_TCE;
}
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

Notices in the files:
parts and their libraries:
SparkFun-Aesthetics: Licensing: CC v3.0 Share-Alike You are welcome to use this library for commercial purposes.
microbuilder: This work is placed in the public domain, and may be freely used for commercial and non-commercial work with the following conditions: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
